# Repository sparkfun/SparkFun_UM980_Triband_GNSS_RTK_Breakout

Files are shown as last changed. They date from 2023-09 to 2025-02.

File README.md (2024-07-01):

SparkFun Triband GNSS RTK Breakout - UM980
===========================================================

SparkFun Triband GNSS RTK Breakout - UM980 (https://www.sparkfun.com/products/23286)

[*SparkFun Triband GNSS RTK Breakout - UM980 (GPS-23286)*](https://www.sparkfun.com/products/23286)

The SparkFun Triband GNSS RTK Breakout features the UM980 GNSS high precision RTK position module from Unicore Communications. The UM980 is a 1408-Channel GNSS Receiver based on the Nebulas IV™ that is able to simultaneously track GPS L1/L2/L5, GLONASS L1/L2, Galileo E1/E5a/E5b/E6, Beidou B1I/B2I/B3I/B1C/B2a/B2b, QZSS L1/L2/L5, and SBAS. With this board, you will be able to know where your (or any object's) X, Y, and Z location is within roughly the width of your fingernail. When an RTK solution is reached, the module can achieve a horizontal accuracy of about 8mm (~0.3 inches) and vertical accuracy of 15mm (~0.59 inches). The UM980 is capable of both rover and base station operations.

We've included a rechargeable backup battery to keep the latest module configuration and satellite data available. This battery helps 'warm-start' the module, decreasing the time-to-first-fix dramatically. This module features a survey-in mode, allowing the module to become a base station and produce RTCM 3.x correction data. A SMA connector is included for a secure connection to a Triband GNSS antenna.

Currently, serial UART is only supported on the UM980 module. All three serial UART ports have been broken out to the USB-C connector via CH340, 4-pin locking JST connector, and BlueSMiRF header. Unique pins have also been broken out to the edge of the board. Various jumpers are also included to configure power and LEDs.

Repository Contents
-------------------

* **.github/workflows** - YAML files used for GitHub Actions and GitHub Pages/mkdocs
* **/Firmware** - UM980 Firmware packages
* **/Documents** - Datasheets and various documents related to the UM980
* **/Hardware** - Eagle files
* **/Software** - Related software for the UM980
* **/docs** - Online documentation files
  * **/assets** - Folder containing all the file assets used for product documentation
    * **/board_files** - Copy of design files used for product documentation
    * **/component_documentation** - Datasheets and manuals for hardware components
    * **/img** - Images for product documentation
  * **/github** - Files stating how to contribute and filing issues used for product documentation
  * **/javascript** - Folder containing custom javascript used for product documentation
  * **/stylesheet** - Folder containing CSS files used for product documentation
* **/overrides** - Customization files used for product documentation
  * **/.icons** - Icons used for GitHub used for product documentation
  * **./partials** - Used for product documentation

Documentation
--------------

* **[Installing an Arduino Library Guide](https://learn.sparkfun.com/tutorials/installing-an-arduino-library)** - Basic information on how to install an Arduino library.
* **[Library](https://github.com/sparkfun/SparkFun_Unicore_GNSS_Arduino_Library/)** - Unicore GNSS Arduino Library
* **[Hookup Guide](https://docs.sparkfun.com/SparkFun_UM980_Triband_GNSS_RTK_Breakout/)** - Hookup guide for the SparkFun Triband GNSS RTK Breakout - UM980.
* **[How to Update Firmware on a Unicore GNSS Receiver](https://docs.sparkfun.com/Update_Firmware_Unicore_GNSS_Receiver/introduction/)** - Tutorial on how to update firmware on a Unicore GNSS Receiver. This is a general tutorial that covers the RTK Torch and UM980 breakout. Note that this information also included in the SparkFun Triband GNSS RTK Breakout - UM980 Hookup Guide.

License Information
-------------------

This product is _**open source**_! 

Various bits of the code have different licenses applied. Anything SparkFun wrote is beerware; if you see me (or any other SparkFun employee) at the local, and you've found our code helpful, please buy us a round!

Please use, reuse, and modify these files as you see fit. Please maintain attribution to SparkFun Electronics and release anything derivative under the same license.

Distributed as-is; no warranty is given.

- Your friends at SparkFun.

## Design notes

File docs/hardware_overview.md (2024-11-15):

In this section, we will highlight the hardware and pins that are broken out on the SparkFun Triband GNSS RTK Breakout - UM980. For more information, check out our [Resources and Going Further](../resources/) for the UM980.

<div style="text-align: center;">
  <table>
    <tr style="vertical-align:middle;">
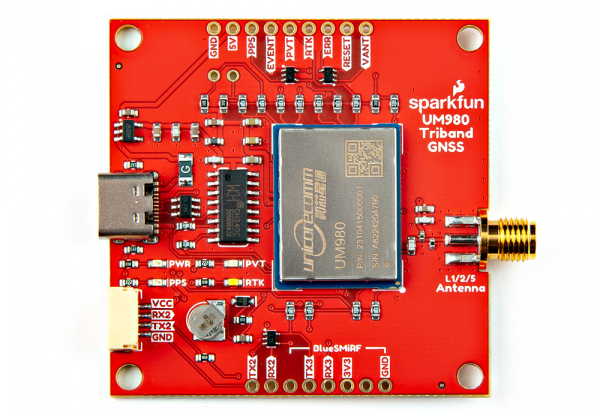
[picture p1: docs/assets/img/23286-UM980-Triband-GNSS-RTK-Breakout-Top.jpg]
     <td style="text-align: center; vertical-align: middle;"></td>
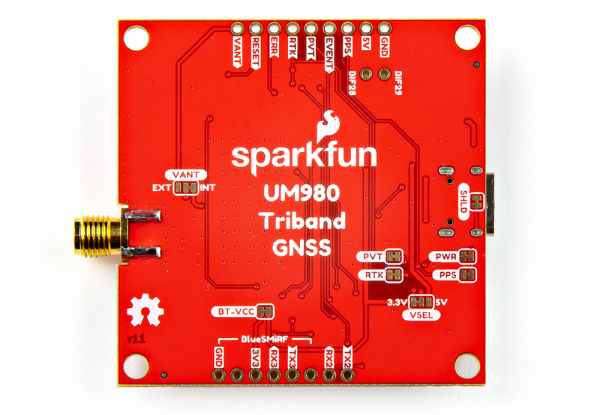
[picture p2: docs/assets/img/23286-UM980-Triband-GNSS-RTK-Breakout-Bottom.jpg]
Bottom View
     <td style="text-align: center; vertical-align: middle;"></td>
    </tr>
    <tr style="vertical-align:middle;">
     <td align="center">Top View</td>
     <td align="center">Bottom View</td>
    </tr>
  </table>
</div>

### UM980 Module

The board breaks out the UM980 which is an all-constellation, all-frequency, high precision RTK positioning module. This module has a low power consumption of about ~480mW.

<div style="text-align: center;">
  <table>
    <tr style="vertical-align:middle;">
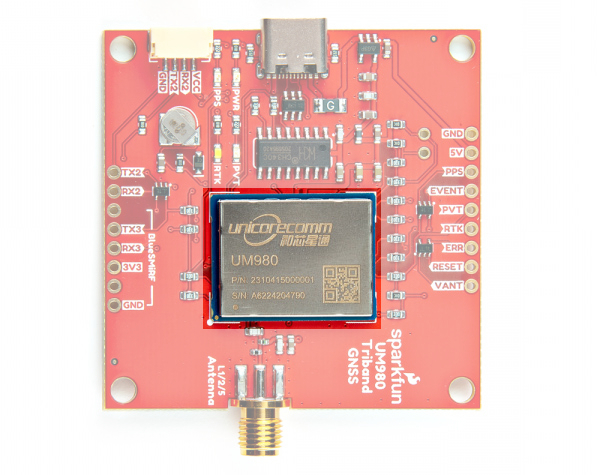
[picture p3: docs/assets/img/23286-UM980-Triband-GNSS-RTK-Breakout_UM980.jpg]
UM980 Module
     <td style="text-align: center; vertical-align: middle;"></td>
    </tr>
  </table>
</div>

The UM980 is a 1408-Channel GNSS Receiver based on the Nebulas IV&trade; that is able to simultaneously track multiple constellation for L1, L2, and L5 bands.

* Concurrent reception of GPS, GLONASS, Galileo, BeiDou, QZSS
    * GPS: L1C/A, L1C<sup>*</sup>, L2P(Y), L2C, L5
    * GLONASS: L1, L2
    * Galileo: E1, E5a, E5b, E6<sup>*</sup>
    * Beidou: B1I, B2I, B3I, B1C, B2a, B2b<sup>*</sup>
    * QZSS: L1/L2/L5
    * SBAS<br/><br/>

<sub>*: Items marked with * are only supported by specific firmware.</sub>

<div style="text-align: center;">
  <table>
    <tr style="vertical-align:middle;">
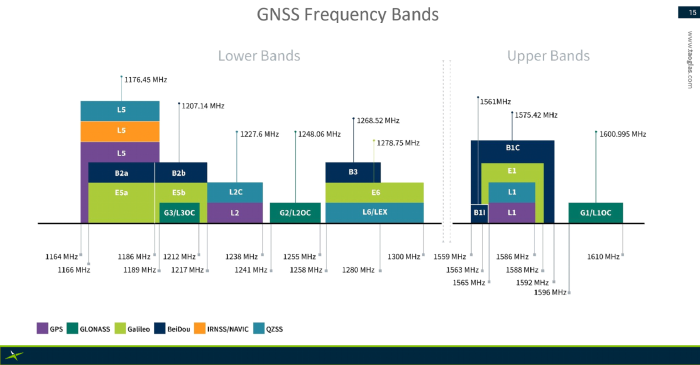
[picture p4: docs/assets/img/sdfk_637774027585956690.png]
L1, L2, L5 GNSS Frequency Bands
     <td style="text-align: center; vertical-align: middle;"></td>
    </tr>
    <tr style="vertical-align:middle;">
     <td style="text-align: center; vertical-align: middle;">Image Courtesy of <a href="https://www.everythingrf.com/community/navigating-the-l1-l2-and-l5-band-options-for-gnss">everythingRF</a></td>
    </tr>
  </table>
</div>

When a RTK solution is reached, the module can achieve a horizontal accuracy of about 8mm (~0.3 inches) and vertical accuracy of 15mm (~0.59 inches). The UM980 is capable of both rover and base station operations. Below are a few specs taken from the datasheet. For more information, check out the related [documents for the UM980 in the Resources](../resources/).

* Horizontal Accuracy
    * Autonomous: 1.5m
    * DGPS: 0.4m
    * RTK: 0.8cm + 1ppm
* Vertical Accuracy
    * Autonomous: 2.5m
    * DGPS: 0.8m
    * RTK: 1.5cm + 1ppm
* 50Hz Data Update Rate<sup>*</sup>
* Time-To-First-Fix:
    * Cold: 30s
    * Warm: 20s
    * Hot: 5s
* CoCom Limits
    * Max Altitude: 18000m
    * Max G: &lt;5G
    * Max Velocity: 515m/s
* Velocity Accuracy (RMS): 0.03m/s
* Time Accuracy (RMS): 20ns<br /><br />

<sub>*: Items marked with * are only supported by specific firmware.</sub>

### Power

There are a variety of power and power-related nets broken out to connectors and through hole pads. Power is regulated down to 3.3V with the AP2122K 3.3V/600mA voltage regulator. The logic levels for the UM980 is 3.3V for the I/O pins.

* **5V** &mdash; Power from the USB C connector's VBUS provides power to the 5V bus. A resettable fuse is connected between the two nets The 5V net is also connected to the edge PTH pin labelled as **5V** and the input of the 3.3V voltage regulator. Care must be taken when connecting to this pin to avoid conflicting voltages between the breakout board and anything connect to the 5V pin. Note that if users cut the default trace on **VSEL** and add solder between the center pad and pad labeled as **5V**, the JST locking connector will provide 5V to any device connected on that port as well.
* **VCC** &mdash; The VCC pin on the JST locking connector provides 3.3V by default to any device that is connected to this port. Users can adjust this voltage by cutting the default trace on the **VSEL** jumper, and adding a solder blob between the center pad and pad labeled as **5V**.
* **3V3** &mdash; The 3V3 pin under the BlueSMiRF provides 3.3V to the any serial device that is connected. If a serial device that is connecting to this port has its own power supply, make sure to cut the trace on the **BT-VCC** jumper on the back to avoid conflicting voltages.
* **VANT** &mdash; The voltage antenna (**VANT**) pin connects to the **VANT** jumper's **EXT** pad. This will provide power to an active antenna on the SMA connector if users cut the default trace on the **VANT** jumper, and add a solder blob between the center pad and pad labeled as **EXT**.
* **GND** &mdash; Of course, is the common, ground voltage (0V reference) for the system.

<div style="text-align: center;">
  <table>
    <tr style="vertical-align:middle;">
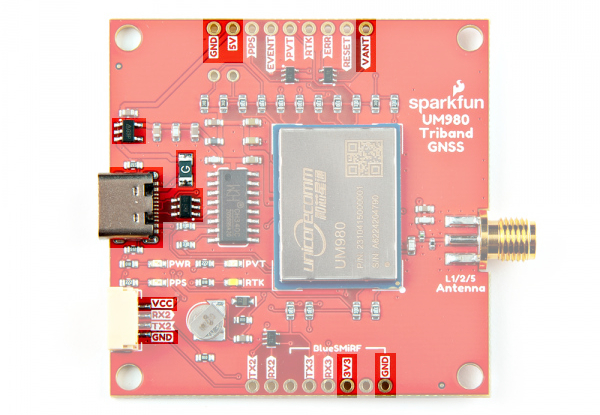
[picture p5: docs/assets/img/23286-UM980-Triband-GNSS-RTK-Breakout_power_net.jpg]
Power Nets Highlighted
     <td style="text-align: center; vertical-align: middle;"></td>
    </tr>
  </table>
</div>

### Backup Battery

The small metal disk is a small 3V/1mAh lithium battery. This battery does not provide power to the IC like the 3.3V system does, but to relevant systems inside the IC that allow for a quick reconnection to satellites. The first time to fix (TTFF) is about ~30 seconds. With the backup battery, the warm start is less than 20 seconds and the hot start is less than 5 seconds.

<div style="text-align: center;">
  <table>
    <tr style="vertical-align:middle;">
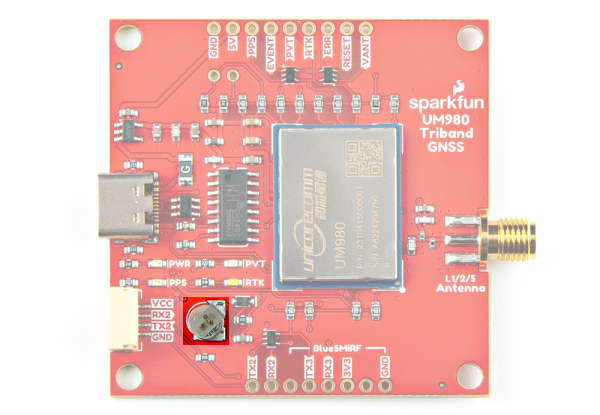
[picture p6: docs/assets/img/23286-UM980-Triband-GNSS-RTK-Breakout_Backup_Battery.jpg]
Backup Battery Highlighted
     <td style="text-align: center; vertical-align: middle;"></td>
    </tr>
  </table>
</div>

### CH340 USB-to-Serial Converter

The top side of the board includes a CH340 USB-to-serial converter connected to the serial UART1 port. The chip can be used to send serial data between the device and computer. You can view the output or configure the device through a serial terminal. When using the UM980 with Unicore's UPrecise Software, you can also initiate firmware updates.

<div style="text-align: center;">
  <table>
    <tr style="vertical-align:middle;">
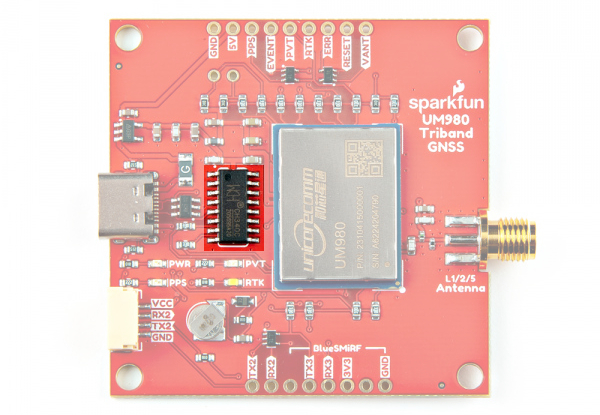
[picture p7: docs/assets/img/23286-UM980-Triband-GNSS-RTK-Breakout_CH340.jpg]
CH340 Highlighted on the TriBand GNSS RTK Breakout Board - UM980
     <td style="text-align: center; vertical-align: middle;"></td>
    </tr>
  </table>
</div>

The CH340 driver should automatically install on most operating systems. However, there is a wide range of operating systems out there. You may need to install drivers the first time you connect the chip to your computer's USB port or when there are operating system updates. For more information, check out our [How to Install CH340 Drivers Tutorial](https://learn.sparkfun.com/tutorials/how-to-install-ch340-drivers).

<div style="text-align: center">
  <table>
    <tr>
      <td style="text-align: center; vertical-align: middle;">
        <a href="https://learn.sparkfun.com/tutorials/how-to-install-ch340-drivers">
          <div style="text-align: center">How to Install CH340 Drivers</div>
          <hr />
          <h3 style="text-align: left">
            <b>How to Install CH340 Drivers</b>
          </h3>
        </a>
      </td>
    </tr>
  </table>
</div>

### Serial UARTs

!!! note
    Current serial UART is only supported on the UM980 module. I<sup>2</sup>C, SPI, and CAN have been reserved on the module but are not currently supported.

There are three serial UART ports available on the breakout board. Serial UART1 is connected to the CH340 USB-to-serial converter as stated earlier. Serial UART2 is connected to the 4-pin locking JST connector. Tx and Rx are also broken out as PTHs. We recommend using a compatible cable to connect to the locking JST connector to save time connecting to a microcontroller. Serial UART3 is connected to the PTH pins labeled as BlueSMiRF on the edge of the board.

<div style="text-align: center;">
  <table>
    <tr style="vertical-align:middle;">
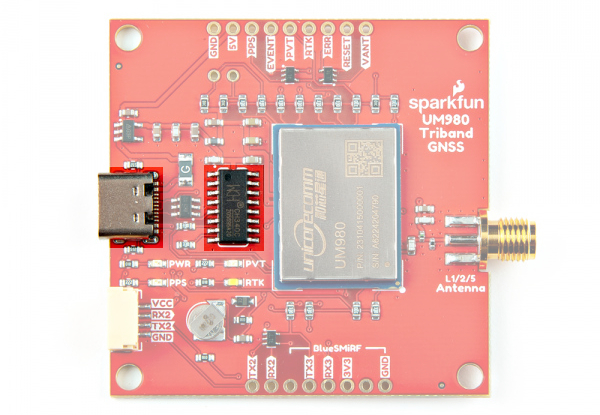
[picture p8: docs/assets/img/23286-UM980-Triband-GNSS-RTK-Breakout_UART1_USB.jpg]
UART1 via USB
     <td style="text-align: center; vertical-align: middle;"></td>
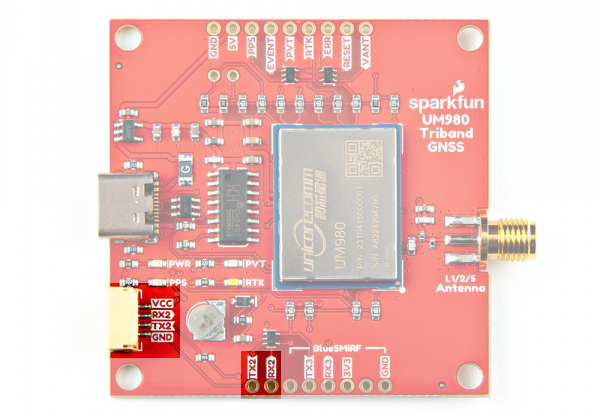
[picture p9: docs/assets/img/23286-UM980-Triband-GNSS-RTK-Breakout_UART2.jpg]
UART2
     <td style="text-align: center; vertical-align: middle;"></td>
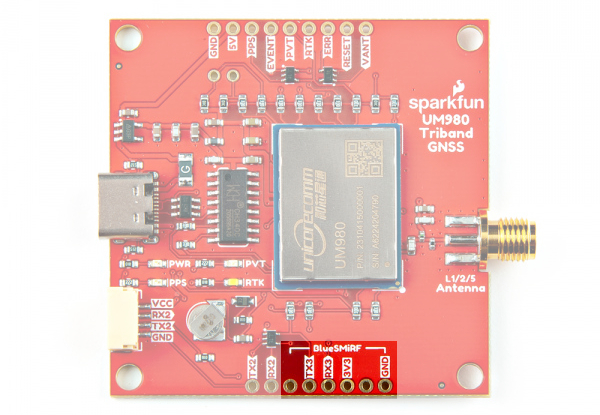
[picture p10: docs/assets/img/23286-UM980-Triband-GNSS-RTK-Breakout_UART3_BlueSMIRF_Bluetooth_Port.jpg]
UART3
     <td style="text-align: center; vertical-align: middle;"></td>
    </tr>
    <tr style="vertical-align:middle;">
     <td align="center">UART1</td>
     <td align="center">UART2</td>
     <td align="center">UART3</td>
    </tr>
  </table>
</div>

!!! note "What is a BlueSMiRF?"
    The BlueSMiRF was a Bluetooth device that was included in SparkFun's catalog. The footprint consists of a 1x6 header for the serial UART and power pins. Note that the arrangement of the header pins is different from USB-to-serial converters (i.e. FTDI Serial Breakout Boards and CH340 Serial Basics Boards).

### SMA Connector

The board is populated with one SMA connector for a secure connection. You will need a multiband GNSS antenna capable of receiving L1, L2, and L5 bands to get the most out of the UM980. Note that this is intended for active antennas. We recommend using the
[GNSS Multi-Band L1/L2/L5 Surveying Antenna - TNC (SPK6618H)](https://www.sparkfun.com/products/21801) as it includes a built-in ground plane and [SMA Male to TNC Male interface cable](https://www.sparkfun.com/products/17833).

<div style="text-align: center;">
  <table>
    <tr style="vertical-align:middle;">
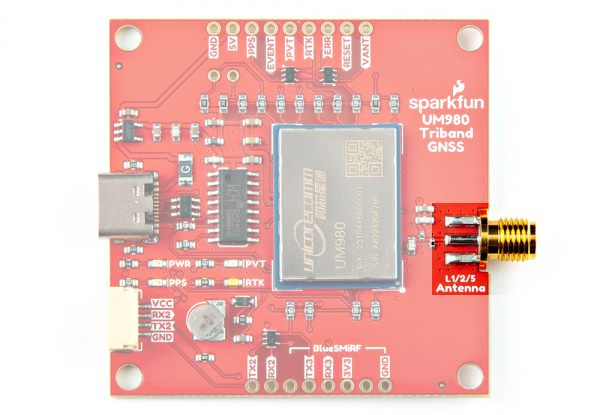
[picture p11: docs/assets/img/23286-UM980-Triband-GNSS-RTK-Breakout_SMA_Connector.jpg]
SMA Connector Highlighted
     <td style="text-align: center; vertical-align: middle;"></td>
    </tr>
  </table>
</div>

### Breakout Pins

Besides the power and serial UART pins, the following pins are also broken out on the edge of the breakout board.

* **PPS** &mdash; The **PPS** output pin provides a pulse per second when there is a satellite lock.  When the UM980 losses a satellite lock, the PPS will continue to blink for about 1 minute. Note that output pulse width and polarity can vary depending on the UM980's configuration. Make sure to check the Unicore Reference Commands Manual for more information.
* **EVENT** &mdash; The **EVENT** input pin and has an adjustable frequency and polarity.
* **PVT** &mdash; The **PVT** pin is a status pin and active high. This outputs high when positioning and low when not positioning. This is connected to an LED as well and will light up whenever the pin is high.
* **RTK** &mdash; The **RTK** pin is a status pin and active high. This outputs high for an RTK fixed solution, and low with other positioning status or no positioning. This is connected to an LED as well and will light up whenever the pin is high.
* **ERR** &mdash; The **ERROR** pin is active high when there is an error or failing self-detection. The pin is low when passing.
* **RESET** &mdash; The **RESET** pin is active low and resets the UM980. The recommended active time should be no less than 5ms.
* **BIF29** &mdash; The **BIF29** stands for the built-in function that was broken out from the UM980&apos;s pin 29. This is connected to a 10k&ohm; pull-up resistor that was recommended as part of the design as a testing point. Note that this pin cannot connect to ground, power, or a peripheral I/O.
* **BIF28** &mdash; The **BIF28** stands for the built-in function that was broken out from the UM980&apos;s pin 28. This is connected to a 10k&ohm; pull-up resistor that was recommended as part of the design as a testing point. Note that this pin cannot connect to ground, power, or a peripheral I/O.

<div style="text-align: center;">
  <table>
    <tr style="vertical-align:middle;">
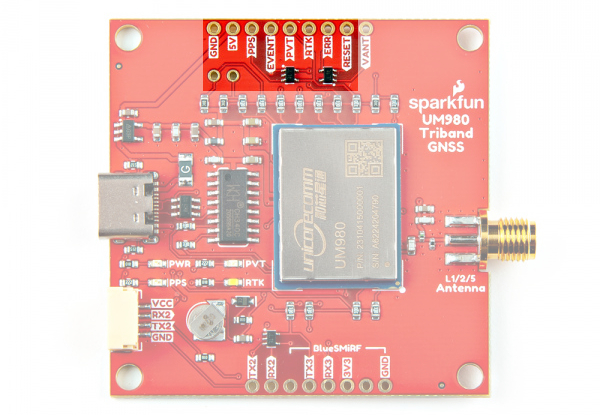
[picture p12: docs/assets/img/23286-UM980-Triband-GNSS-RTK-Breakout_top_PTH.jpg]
     <td style="text-align: center; vertical-align: middle;"></td>
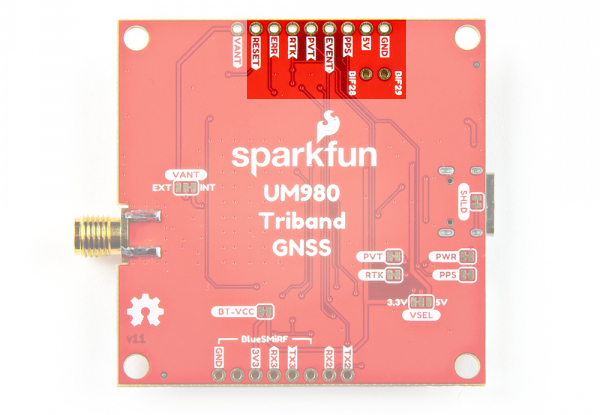
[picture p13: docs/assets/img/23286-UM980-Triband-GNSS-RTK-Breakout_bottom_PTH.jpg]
Bottom View
     <td style="text-align: center; vertical-align: middle;"></td>
    </tr>
    <tr style="vertical-align:middle;">
     <td align="center">Top View of Breakout Pins</td>
     <td align="center">Bottom View of Breakout Pins</td>
    </tr>
  </table>
</div>

### LEDs

The board includes the following status LEDs as indicated in the image below.

* **PWR** &mdash; The power LED is connected to 3.3V and lights up with there is power on the board. Users can disable this LED by cutting the trace connecting the **PWR** jumper.
* **PVT** &mdash; The PVT LED is connected to the PVT pin. This lights up when positioning. Users can disable this LED by cutting the trace connecting the **PVT** jumper.
* **PPS** &mdash; By default, the **PPS** LED will blink when there is a satellite lock. When the UM980 losses a satellite lock, the PPS will continue to blink for about 1 minute. Note that output can vary depending on the UM980's configuration. Make sure to check the Unicore Reference Commands Manual for more information. Users can disable this LED by cutting the trace connecting the **PPS** jumper.
* **RTK** &mdash; The RTK LED lights up when there is an RTK fixed solution. Users can disable this LED by cutting the trace connecting the **RTK** jumper.

<div style="text-align: center;">
  <table>
    <tr style="vertical-align:middle;">
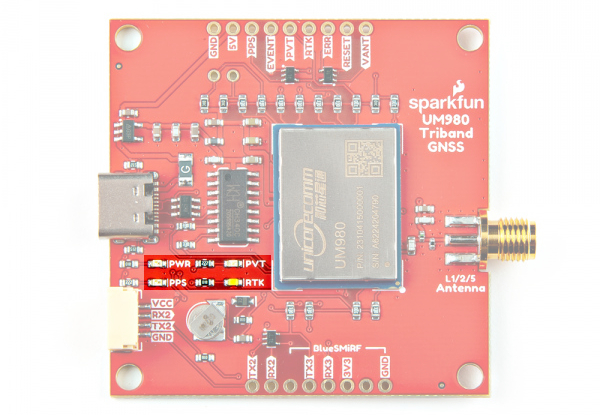
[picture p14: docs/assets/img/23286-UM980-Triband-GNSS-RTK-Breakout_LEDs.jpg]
LEDs Highlighted
     <td style="text-align: center; vertical-align: middle;"></td>
    </tr>
  </table>
</div>

### Jumpers

!!!note
    If this is your first time working with jumpers, check out the [How to Work with Jumper Pads and PCB Traces](https://learn.sparkfun.com/tutorials/how-to-work-with-jumper-pads-and-pcb-traces/all) tutorial for more information.

There are a few jumper pads available on the bottom of the board.

* **SHLD** &mdash; This jumper connects the USB Type C connector's shield pin to GND. Cut this to isolate the USB Type C connector's shield pin. This is for advanced users that want to ground their board to their enclosure instead of the ground plane.
* **VSEL** &mdash; This three way jumper sets voltage to the locking JST connector. By default, this is set to 3.3V. Cutting a trace and adding a solder blob between the center pad and the pad labeled as **5V** will set the voltage on the locking JST connector to 5V.
* **PWR** &mdash; By default, this jumper is closed. Cut this trace to disable the power LED that is connected to 3.3V.
* **PVT** &mdash; By default, this jumper is closed. Cut this trace to disable the PVT LED connected to PVT.
* **PPS** &mdash; By default, this jumper is closed. Cut this trace to disable the PPS LED connected to PPS.
* **RTK** &mdash; By default, this jumper is closed. Cut this trace to disable the RTK LED connected to RTK.
* **BT-VCC** &mdash; By default, this jumper is closed and connected to 3.3V. If a serial device that is connecting to this port has its own power supply, cut this trace to avoid conflicting voltages.
* **VANT** &mdash; This three way jumper sets the voltage source for the active antenna. By default, this is connected to the INT and uses voltage provided from the board (specifically the UM980's _VCC_RF_ pin). Cut this trace and add a solder blob between the center pad and the pad labeled as **EXT** to provide external power to your active antenna. Make sure to also provide power on the VANT PTH and connect GND from the external power supply the rest of the GND plane.

<div style="text-align: center;">
  <table>
    <tr style="vertical-align:middle;">
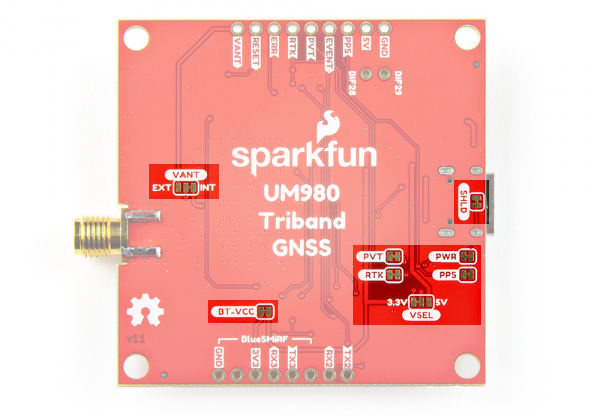
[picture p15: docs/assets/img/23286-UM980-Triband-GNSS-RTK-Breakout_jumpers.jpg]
Jumpers Highlighted
     <td style="text-align: center; vertical-align: middle;"></td>
    </tr>
  </table>
</div>

### 3D Model

A 3D model of the board and components were exported to a STEP file using KiCad.

<!-- Import the component -->
<script type="module" src="https://ajax.googleapis.com/ajax/libs/model-viewer/3.5.0/model-viewer.min.js"></script>

<div style="text-align: center;">
    <model-viewer src="../assets/3d_model/SparkFun_GNSS_UM980_3D_model.glb" camera-controls poster="../assets/3d_model/SparkFun_GNSS_UM980_3D_image.png" environment-image="legacy" shadow-intensity="1.58" exposure="0.64" shadow-softness="0.24" tone-mapping="neutral" camera-orbit="-46.67deg 57.14deg 153.3m" field-of-view="30deg" style="width: 750px; height: 500px;">
    </model-viewer>
</div>
<br />
<div style="text-align: center">
    <a href="../assets/3d_model/SparkFun_GNSS_UM980_3D_model.step" target="stp_file" class="md-button">Click Here for the STEP File</a>
</div>

###Board Dimensions

The board is 2.0" x 2.0" (50.8mm x 50.8mm). There are 4x mounting holes by each corner of the board.

<div style="text-align: center;">
  <table>
    <tr style="vertical-align:middle;">
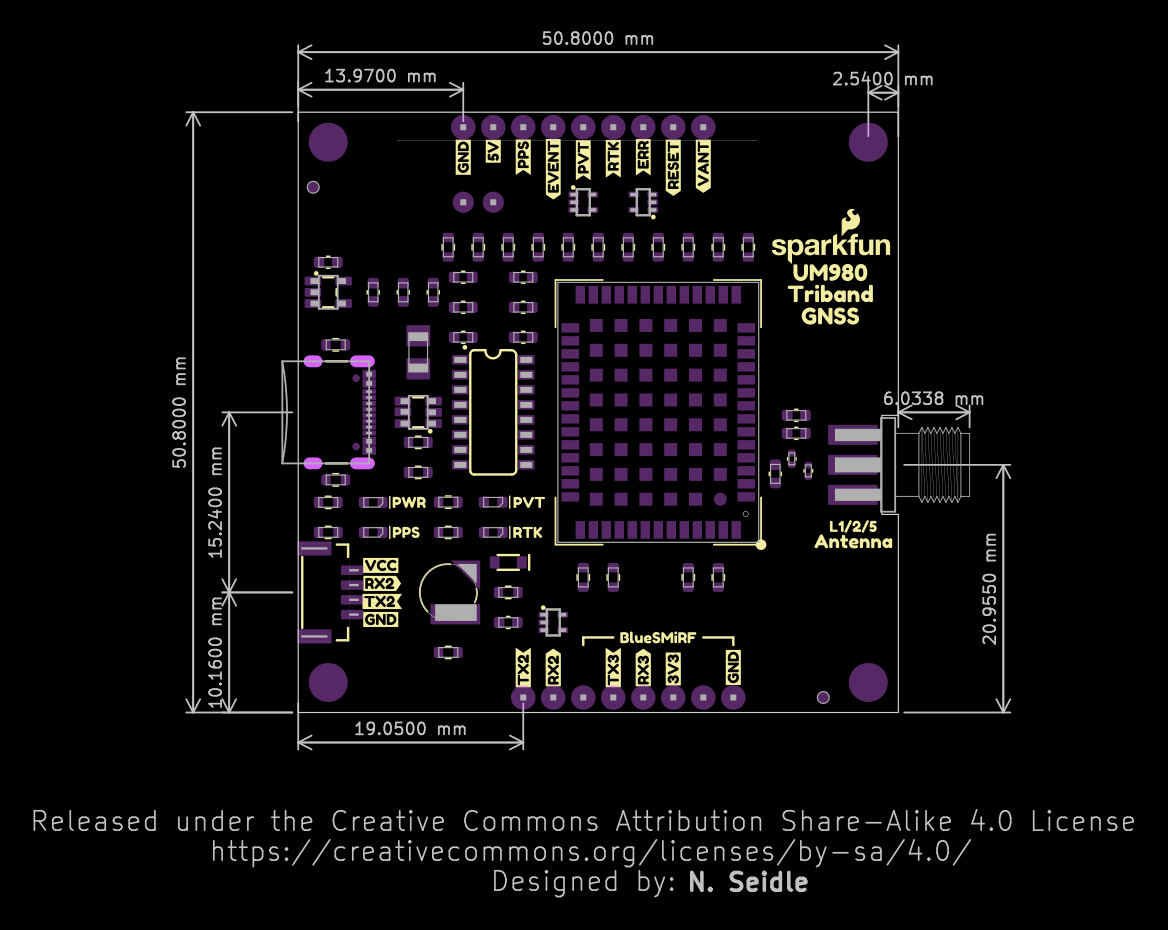
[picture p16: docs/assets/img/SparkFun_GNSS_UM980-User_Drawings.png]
Board Dimensions
     <td style="text-align: center; vertical-align: middle;"></td>
    </tr>
  </table>
</div>

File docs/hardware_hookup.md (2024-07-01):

In this section, we'll go over how to connect the Triband GNSS Antenna, GNSS RTK Breakout - UM980, and IoT RedBoard - ESP32 for embedded systems. Of course, you can also connect the UM980 directly to your computer without the need for a microcontroller if you decide to use the UPrecise Software as well.

### L1/L2/L5 Multiband GNSS Antenna

Connect a compatible multi-band antenna that is capable of receiving L1, L2, and L5 bands. In this case, we used the "GNSS Multi-Band L1/L2/L5 Surveying Antenna - TNC (SPK6618H)." This also has a ground plane embedded in the antenna. Insert the TNC side of the interface cable into the antenna's TNC connector. Secure the connection by tightening the screw until it is finger-tight. Then insert the SMA side of the interface cable into the Triband GNSS RTK Breakout's SMA connector. Secure the connection by using the SMA's hex nut until it is finger-tight.

<div style="text-align: center;">
  <table>
    <tr style="vertical-align:middle;">
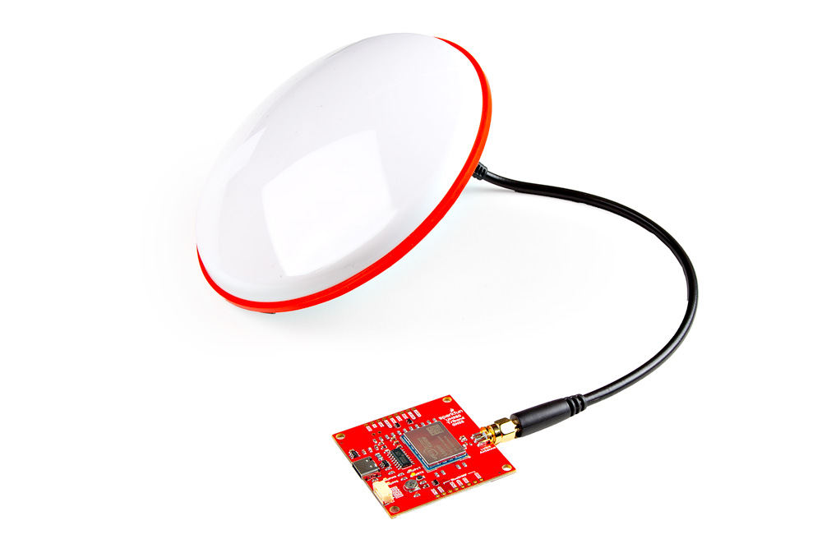
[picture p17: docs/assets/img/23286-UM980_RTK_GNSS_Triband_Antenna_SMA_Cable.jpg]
Adapter cable between Antenna and Breakout Board
     <td style="text-align: center; vertical-align: middle;"></td>
    </tr>
  </table>
</div>

!!! note
    For users that are using a different multiband antenna, you may need to include a [antenna ground plate](https://www.sparkfun.com/products/17519) to get the most of the multi-band antenna.

!!! note
    Not all multiband antennas are made the same! Make sure that you are connecting a multi-band antenna that is capable of receiving L1/L2/L5 signals when using the Triband GNSS RTK Breakout - UM980.

### Microcontroller

!!! note
    The Arduino Library was written and tested with the ESP32 processor. We recommend using the IoT RedBoard - ESP32 for the scope of this tutorial.

For users using the breakout board in embedded applications, you will need to plug in the JST-GHR-04V Cable to the Triband GNSS RTK Breakout - UM980. You will then need to connect the other end to a microcontroller to process the data. In this case, we used the IoT RedBoard - ESP32.

<div style="text-align: center;">
    <table>
        <tr>
            <th style="text-align: center; border: solid 1px #cccccc;">IoT RedBoard - ESP32
            </th>
            <th style="text-align: center; border: solid 1px #cccccc;"> Triband GNSS RTK Breakout - UM980
            </th>
        </tr>
        <tr>
            <td style="text-align: center; border: solid 1px #cccccc;" bgcolor="#f2dede"><font color="#000000">3V3</font>
            </td>
            <td style="text-align: center; border: solid 1px #cccccc;" bgcolor="#f2dede"><font color="#000000">3.3V</font>
            </td>
        </tr>
        <tr>        
            <td style="text-align: center; border: solid 1px #cccccc;" bgcolor="#d4edda"><font color="#000000">UART1_TX (D4)</font>
            </td>
            <td style="text-align: center; border: solid 1px #cccccc;" bgcolor="#d4edda"><font color="#000000">RX2</font>
            </td>
        </tr>
        <tr>        
            <td style="text-align: center; border: solid 1px #cccccc;" bgcolor="#ffdaaf"><font color="#000000">UART1_RX (D13)</font>
            </td>
            <td style="text-align: center; border: solid 1px #cccccc;" bgcolor="#ffdaaf"><font color="#000000">TX2</font>
            </td>
        </tr>
        <tr>
            <td style="text-align: center; border: solid 1px #cccccc;" bgcolor="#DDDDDD"><font color="#000000">GND</font>
            </td>
            <td style="text-align: center; border: solid 1px #cccccc;" bgcolor="#DDDDDD"><font color="#000000">GND</font>
            </td>
        </tr>
    </table>
</div>

<div style="text-align: center;">
  <table>
    <tr style="vertical-align:middle;">
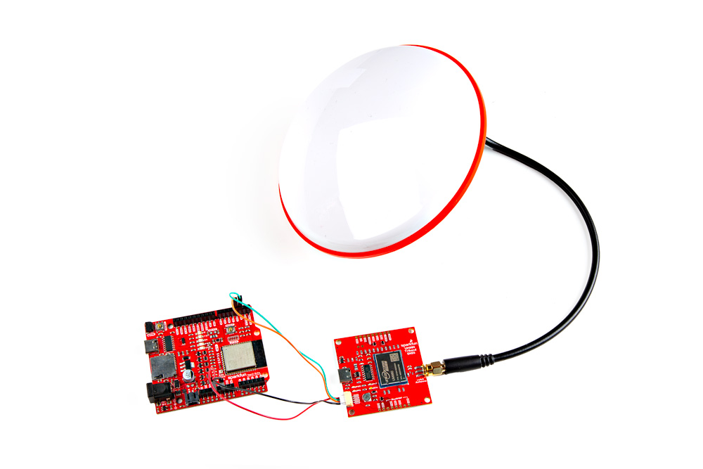
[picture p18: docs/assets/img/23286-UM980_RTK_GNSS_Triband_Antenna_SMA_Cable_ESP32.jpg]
UM980 to Microcontroller with USB
     <td style="text-align: center; vertical-align: middle;"></td>
    </tr>
  </table>
</div>

### USB to Microcontroller

To power and program the IoT RedBoard - ESP32, users will just need to insert the Type C side of the cable to the development board. The other end will connect to a computer's USB port.

<div style="text-align: center;">
  <table>
    <tr style="vertical-align:middle;">
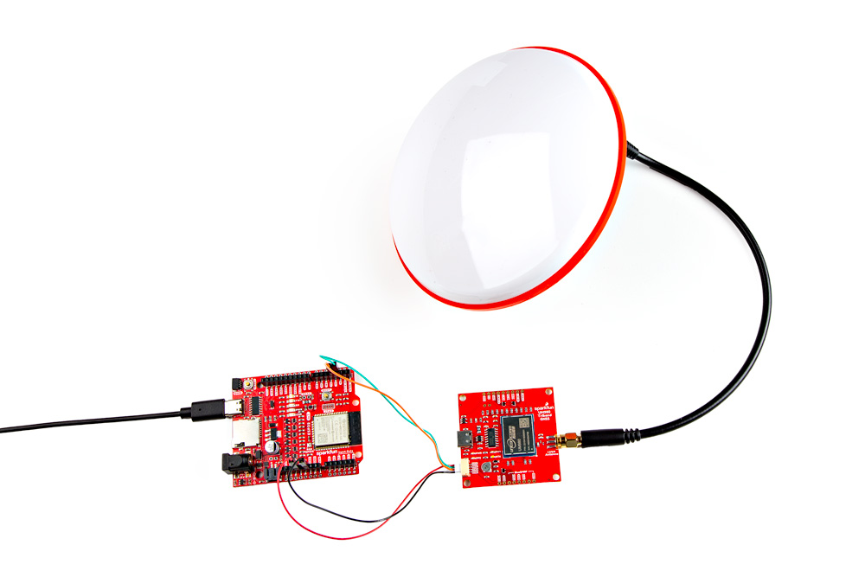
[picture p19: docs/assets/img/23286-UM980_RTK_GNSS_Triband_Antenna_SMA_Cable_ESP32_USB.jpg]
USB Cable Inserted into IoT RedBoard - ESP32 and Triband GNSS RTK Breakout UM980
     <td style="text-align: center; vertical-align: middle;"></td>
    </tr>
  </table>
</div>

### USB to Triband GNSS RTK Breakout - UM980

For users that simply want to connect to the board via USB, you will insert a USB C cable into the USB connector. Then connect the other end to your computer USB port.

<div style="text-align: center;">
  <table>
    <tr style="vertical-align:middle;">
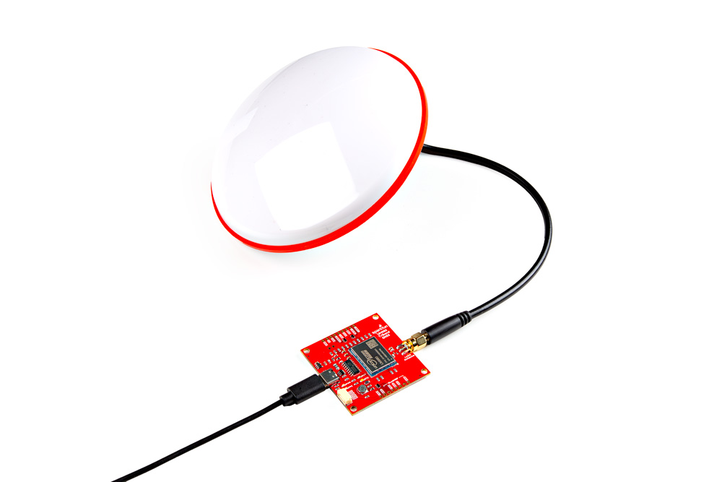
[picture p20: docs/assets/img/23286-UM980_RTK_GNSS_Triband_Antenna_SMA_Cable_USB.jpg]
USB Cable Inserted into Triband GNSS RTK Breakout UM980
     <td style="text-align: center; vertical-align: middle;"></td>
    </tr>
  </table>
</div>

### Connecting via PTH

For temporary connections to the PTHs, you could use IC hooks to test out the pins. However, you'll need to solder headers or wires of your choice to the board for a secure connection. You can choose between a combination of [header pins and jumper wires](https://learn.sparkfun.com/tutorials/how-to-solder-through-hole-soldering/all), or [stripping wire and soldering the wire](https://learn.sparkfun.com/tutorials/working-with-wire/all) directly to the board.

<div class="grid cards col-4" markdown>

-   <a href="https://learn.sparkfun.com/tutorials/how-to-solder-through-hole-soldering/all">
      <figure markdown>
        How to Solder: Through Hole Soldering
      </figure>
    </a>

    ---

    <a href="https://learn.sparkfun.com/tutorials/how-to-solder-through-hole-soldering/all">
      <b>How to Solder: Through Hole Soldering</b>
    </a>
<!-- ----------WHITE SPACE BETWEEN GRID CARDS---------- -->

-   <a href="https://learn.sparkfun.com/tutorials/working-with-wire/all">
      <figure markdown>
        Working with Wire
      </figure>
    </a>

    ---

    <a href="https://learn.sparkfun.com/tutorials/working-with-wire/all">
      <b>Working with Wire</b>
    </a>
<!-- ----------WHITE SPACE BETWEEN GRID CARDS---------- -->
</div>

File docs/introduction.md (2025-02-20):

The [SparkFun Triband GNSS RTK Breakout features the UM980](https://www.sparkfun.com/products/23286) GNSS high precision RTK position module from Unicore Communications. The UM980 is a 1408-Channel GNSS Receiver based on the Nebulas IV&trade; that is able to simultaneously track GPS L1/L2/L5, GLONASS L1/L2, Galileo E1/E5a/E5b/E6, Beidou B1I/B2I/B3I/B1C/B2a/B2b, QZSS L1/L2/L5, and SBAS. With this board, you will be able to know where your (or any object's) X, Y, and Z location is within roughly the width of your fingernail. When an RTK solution is reached, the module can achieve a horizontal accuracy of about 8mm (~0.3 inches) and vertical accuracy of 15mm (~0.59 inches). The UM980 is capable of both rover and base station operations.

<center>
<div class="grid cards" style="width:500px;" markdown>

-   <a href="https://www.sparkfun.com/products/23286">
      <figure markdown>
        SparkFun Triband GNSS RTK Breakout - UM980
      </figure>
    </a>

    ---

    <a href="https://www.sparkfun.com/products/23286">
      <b>SparkFun Triband GNSS RTK Breakout - UM980</b>
      <br />
      GPS-23286
      <br />
      <center>[Purchase from SparkFun :fontawesome-solid-cart-plus:](https://www.sparkfun.com/products/23286){ .md-button .md-button--primary }</center>
    </a>

</div>
</center>

<div style="text-align: center;">
  <iframe width="560" height="315" src="https://www.youtube.com/embed/JRmVSYMMBFU?si=3qFl3sWRnnz5FLNi" title="YouTube video player" frameborder="0" allow="accelerometer; autoplay; clipboard-write; encrypted-media; gyroscope; picture-in-picture; web-share" allowfullscreen></iframe>
</div>

In this tutorial, we'll go over the hardware and how to hookup the breakout board. We will also go over the Arduino examples to get started.

### Required Materials

To follow along with this tutorial, you will need the following materials. You may not need everything though depending on what you have. Add it to your cart, read through the guide, and adjust the cart as necessary.

* 1x [SparkFun IoT RedBoard - ESP32 Development Board [WRL-19177]](https://www.sparkfun.com/products/19177)
* 1x [Reversible USB A to C Cable - 0.8m [CAB-15425]](https://www.sparkfun.com/products/15425)
* 1x [Breadboard to JST-GHR-04V Cable - 4-Pin x 1.25mm Pitch [CAB-17240]](https://www.sparkfun.com/products/17240)
* 1x [SparkFun Triband GNSS RTK Breakout - UM980 [GPS-23286]](https://www.sparkfun.com/products/23286)
* 1x [Reinforced Interface Cable - SMA Male to TNC Male (10m) [CAB-21740]](https://www.sparkfun.com/products/21740)
* 1x [GNSS Multi-Band L1/L2/L5 Surveying Antenna - TNC (SPK6618H) [GPS-21801]](https://www.sparkfun.com/products/21801)

<div class="grid cards col-4" markdown>

<!-- ----------WHITE SPACE BETWEEN PRODUCTS---------- -->
-   <a href="https://www.sparkfun.com/products/19177">
      <figure markdown>
        SparkFun IoT RedBoard - ESP32 Development Board
      </figure>
    </a>

    ---

    <a href="https://www.sparkfun.com/products/19177">
      <b>SparkFun IoT RedBoard - ESP32 Development Board</b>
      <br />
      WRL-19177
    </a>
<!-- ----------WHITE SPACE BETWEEN PRODUCTS---------- -->
-   <a href="https://www.sparkfun.com/products/15425">
      <figure markdown>
        Reversible USB A to C Cable - 0.8m
      </figure>
    </a>

    ---

    <a href="https://www.sparkfun.com/products/15425">
      <b>Reversible USB A to C Cable - 0.8m</b>
      <br />
      CAB-15425
    </a>
<!-- ----------WHITE SPACE BETWEEN PRODUCTS---------- -->
-   <a href="https://www.sparkfun.com/products/23286">
      <figure markdown>
        SparkFun Triband GNSS RTK Breakout - UM980
      </figure>
    </a>

    ---

    <a href="https://www.sparkfun.com/products/23286">
      <b>SparkFun Triband GNSS RTK Breakout - UM980</b>
      <br />
      GPS-23286
    </a>
<!-- ----------WHITE SPACE BETWEEN PRODUCTS---------- -->
-   <a href="https://www.sparkfun.com/products/17240">
      <figure markdown>
        Breadboard to JST-GHR-04V Cable - 4-Pin x 1.25mm Pitch
      </figure>
    </a>

    ---

    <a href="https://www.sparkfun.com/products/17240">
      <b>Breadboard to JST-GHR-04V Cable - 4-Pin x 1.25mm Pitch</b>
      <br>
      CAB-17240
    </a>
<!-- ----------WHITE SPACE BETWEEN PRODUCTS---------- -->
-   <a href="https://www.sparkfun.com/products/21740">
      <figure markdown>
        Reinforced Interface Cable - SMA Male to TNC Male (10m)
      </figure>
    </a>

    ---

    <a href="https://www.sparkfun.com/products/21740">
      <b>Reinforced Interface Cable - SMA Male to TNC Male (10m)</b>
      <br>
      CAB-21740
    </a>
<!-- ----------WHITE SPACE BETWEEN PRODUCTS---------- -->
-   <a href="https://www.sparkfun.com/products/21801">
      <figure markdown>
        GNSS Multi-Band L1/L2/L5 Surveying Antenna - TNC (SPK6618H)
      </figure>
    </a>

    ---

    <a href="https://www.sparkfun.com/products/21801">
      <b>GNSS Multi-Band L1/L2/L5 Surveying Antenna - TNC (SPK6618H)</b>
      <br>
      GPS-21801
    </a>
<!-- ----------WHITE SPACE BETWEEN PRODUCTS---------- -->
</div>

### GNSS Accessories &nbsp;_(Optional)_

Depending on your setup, you may need the following mounting hardware. Note that the antenna ground plate is needed for tri-band antennas that do not have a ground plane.

* [GNSS Magnetic Mount [PRT-21257]](https://www.sparkfun.com/products/21257)
* [GNSS Antenna Mounting Hardware Kit [KIT-22197]](https://www.sparkfun.com/products/22197)
* [GPS Antenna Ground Plate [GPS-17519]](https://www.sparkfun.com/products/17519)

<div class="grid cards col-4" markdown>

-   <a href="https://www.sparkfun.com/products/21257">
      <figure markdown>
        GNSS Magnetic Antenna Mount - 5/8
      <br />
      TOL-21257
    </a>
<!-- ----------WHITE SPACE BETWEEN PRODUCTS---------- -->
-   <a href="https://www.sparkfun.com/products/22197">
      <figure markdown>
        GNSS Antenna Mounting Hardware Kit
      </figure>
    </a>

    ---

    <a href="https://www.sparkfun.com/products/22197">
      <b>GNSS Antenna Mounting Hardware Kit</b>
      <br />
      KIT-22197
    </a>
<!-- ----------WHITE SPACE BETWEEN PRODUCTS---------- -->
-   <a href="https://www.sparkfun.com/products/17519">
      <figure markdown>
        GPS Antenna Ground Plate
      </figure>
    </a>

    ---

    <a href="https://www.sparkfun.com/products/17519">
      <b>GPS Antenna Ground Plate</b>
      <br />
      GPS-17519
    </a>
<!-- ----------WHITE SPACE BETWEEN PRODUCTS---------- -->

</div>

### Radios &nbsp;_(Optional)_

For users that require radios to transmit RTK correction data, you could use the following radios.

* [SiK Telemetry Radio V3 - 915MHz, 100mW [WRL-19032]](https://www.sparkfun.com/products/19032)
* [SparkFun LoRaSerial Kit - 915MHz (Enclosed) [WRL-20029]](https://www.sparkfun.com/products/20029)

<div class="grid cards col-4" markdown>

-   <a href="https://www.sparkfun.com/products/19032">
      <figure markdown>
        SiK Telemetry Radio V3 - 915MHz, 100mW
      </figure>
    </a>

    ---

    <a href="https://www.sparkfun.com/products/19032">
      <b>SiK Telemetry Radio V3 - 915MHz, 100mW</b>
      <br />
      WRL-19032
    </a>
<!-- ----------WHITE SPACE BETWEEN PRODUCTS---------- -->
-   <a href="https://www.sparkfun.com/products/20029">
      <figure markdown>
        SparkFun LoRaSerial Kit - 915MHz (Enclosed)
      </figure>
    </a>

    ---

    <a href="https://www.sparkfun.com/products/20029">
      <b>SparkFun LoRaSerial Kit - 915MHz (Enclosed)</b>
      <br />
      WRL-20029
    </a>
<!-- ----------WHITE SPACE BETWEEN PRODUCTS---------- -->

</div>

### Tools &nbsp;_(Optional)_

You will need a soldering iron, solder, and [general soldering accessories](https://www.sparkfun.com/categories/49) for a secure connection when using the plated through holes.

* [Soldering Iron [TOL-14456]](https://www.sparkfun.com/products/14456)
* [Solder Lead Free - 15-gram Tube [TOL-9163]](https://www.sparkfun.com/products/9163)
* [Flush Cutters - Xcelite [TOL-14782]](https://www.sparkfun.com/products/14782)
* [Hook-Up Wire - Assortment (Stranded, 22 AWG) [PRT-11375]](https://www.sparkfun.com/products/11375)
* [Wire Stripper - 20-30 AWG Solid (22-32 AWG Stranded) [TOL-22263]](https://www.sparkfun.com/products/22263)

<div class="grid cards col-4" markdown>

-   <a href="https://www.sparkfun.com/products/14456">
      <figure markdown>
        Soldering Iron - 60W (Adjustable Temperature)
      </figure>
    </a>

    ---

    <a href="https://www.sparkfun.com/products/14456">
      <b>Soldering Iron - 60W (Adjustable Temperature)</b>
      <br />
      TOL-14456
    </a>
<!-- ----------WHITE SPACE BETWEEN PRODUCTS---------- -->
-   <a href="https://www.sparkfun.com/products/9163">
      <figure markdown>
        Solder Lead Free - 15-gram Tube
      </figure>
    </a>

    ---

    <a href="https://www.sparkfun.com/products/9163">
      <b>Solder Lead Free - 15-gram Tube</b>
      <br>
      TOL-09163
    </a>
<!-- ----------WHITE SPACE BETWEEN PRODUCTS---------- -->
-   <a href="https://www.sparkfun.com/products/11375">
      <figure markdown>
        Hook-Up Wire - Assortment (Stranded, 22 AWG)
      </figure>
    </a>

    ---

    <a href="https://www.sparkfun.com/products/11375">
      <b>Hook-Up Wire - Assortment (Stranded, 22 AWG)</b>
      <br />
      PRT-11375
    </a>
<!-- ----------WHITE SPACE BETWEEN PRODUCTS---------- -->
-   <a href="https://www.sparkfun.com/products/22263">
      <figure markdown>
        Wire Stripper - 20-30 AWG Solid (22-32 AWG Stranded)
      </figure>
    </a>

    ---

    <a href="https://www.sparkfun.com/products/22263">
      <b>Wire Stripper - 20-30 AWG Solid (22-32 AWG Stranded)</b>
      <br />
      TOL-22263
    </a>
<!-- ----------WHITE SPACE BETWEEN PRODUCTS---------- -->
-   <a href="https://www.sparkfun.com/products/14782">
      <figure markdown>
        Flush Cutters - Xcelite
      </figure>
    </a>

    ---

    <a href="https://www.sparkfun.com/products/14782">
      <b>Flush Cutters - Xcelite</b>
      <br />
      TOL-14782
    </a>
<!-- ----------WHITE SPACE BETWEEN PRODUCTS---------- -->
</div>

### Prototyping Accessories &nbsp;_(Optional)_

As listed earlier, we recommend using the 4-pin JST-GHR-04V cable to connect directly to the IoT RedBoard - ESP32's female header pins. However, you could also use IC hooks for a temporary connection depending on your setup and what you have available. For those that prefer to the 0.1" spaced PTH, you will want to solder header pins for a secure connection.

* [Breadboard - Self-Adhesive (White) [PRT-12002]](https://www.sparkfun.com/products/12002)
* [IC Hook with Pigtail [CAB-09741]](https://www.sparkfun.com/products/9741)
* [Break Away Headers - Straight [PRT-00116]](https://www.sparkfun.com/products/116)
* [Female Headers [PRT-00115]](https://www.sparkfun.com/products/115)
* [Jumper Wires Premium 6" M/M Pack of 10 [PRT-08431]](https://www.sparkfun.com/products/8431)

<div class="grid cards col-4" markdown>
<!-- ----------WHITE SPACE BETWEEN PRODUCTS---------- -->
-   <a href="https://www.sparkfun.com/products/12002">
      <figure markdown>
        Breadboard - Self-Adhesive (White)
      </figure>
    </a>

    ---

    <a href="https://www.sparkfun.com/products/12002">
      <b>Breadboard - Self-Adhesive (White)</b>
      <br />
      PRT-12002
    </a>
<!-- ----------WHITE SPACE BETWEEN PRODUCTS---------- -->
-   <a href="https://www.sparkfun.com/products/9741">
      <figure markdown>
        IC Hook with Pigtail
      </figure>
    </a>

    ---

    <a href="https://www.sparkfun.com/products/9741">
      <b>IC Hook with Pigtail</b>
      <br>
      CAB-09741
    </a>
<!-- ----------WHITE SPACE BETWEEN PRODUCTS---------- -->
-   <a href="https://www.sparkfun.com/products/116">
      <figure markdown>
        Break Away Headers - Straight
      </figure>
    </a>

    ---

    <a href="https://www.sparkfun.com/products/116">
      <b>Break Away Headers - Straight</b>
      <br />
      PRT-00116
    </a>
<!-- ----------WHITE SPACE BETWEEN PRODUCTS---------- -->
-   <a href="https://www.sparkfun.com/products/115">
      <figure markdown>
        Female Headers
      </figure>
    </a>

    ---

    <a href="https://www.sparkfun.com/products/115">
      <b>Female Headers</b>
      <br />
      PRT-00115
    </a>
<!-- ----------WHITE SPACE BETWEEN PRODUCTS---------- -->
-   <a href="https://www.sparkfun.com/products/8431">
      <figure markdown>
        Jumper Wires Premium 6
      <br />
      PRT-08431
    </a>
<!-- ----------WHITE SPACE BETWEEN PRODUCTS---------- -->
</div>

### Suggested Reading

If you aren’t familiar with the following concepts, we also recommend checking out a few of these tutorials before continuing.

<div class="grid cards col-4" markdown>
<!-- ----------WHITE SPACE BETWEEN GRID CARDS---------- -->
-   <a href="https://learn.sparkfun.com/tutorials/9">
      <figure markdown>
        GPS Basics
      </figure>
    </a>

    ---

    <a href="https://learn.sparkfun.com/tutorials/9">
      <b>GPS Basics</b>
    </a>
<!-- ----------WHITE SPACE BETWEEN GRID CARDS---------- -->
-   <a href="https://learn.sparkfun.com/tutorials/iot-redboard-esp32-development-board-hookup-guide">
      <figure markdown>
        IoT RedBoard ESP32 Development Board Hookup Guide
      </figure>
    </a>

    ---

    <a href="https://learn.sparkfun.com/tutorials/iot-redboard-esp32-development-board-hookup-guide">
      <b>IoT RedBoard ESP32 Development Board Hookup Guide</b>
    </a>
<!-- ----------WHITE SPACE BETWEEN GRID CARDS---------- -->
-   <a href="https://learn.sparkfun.com/tutorials/installing-arduino-ide">
      <figure markdown>
        Installing Arduino IDE
      </figure>
    </a>

    ---

    <a href="https://learn.sparkfun.com/tutorials/installing-arduino-ide">
      <b>Installing Arduino IDE</b>
    </a>
<!-- ----------WHITE SPACE BETWEEN GRID CARDS---------- -->
-   <a href="https://learn.sparkfun.com/tutorials/installing-board-definitions-in-the-arduino-ide">
      <figure markdown>
        Installing Board Definitions in the Arduino IDE
      </figure>
    </a>

    ---

    <a href="https://learn.sparkfun.com/tutorials/installing-board-definitions-in-the-arduino-ide">
      <b>Installing Board Definitions in the Arduino IDE</b>
    </a>
<!-- ----------WHITE SPACE BETWEEN GRID CARDS---------- -->
-   <a href="https://learn.sparkfun.com/tutorials/how-to-solder-through-hole-soldering">
      <figure markdown>
        How to Solder: Through-Hole Soldering
      </figure>
    </a>

    ---

    <a href="https://learn.sparkfun.com/tutorials/how-to-solder-through-hole-soldering">
      <b>How to Solder: Through-Hole Soldering</b>
    </a>
<!-- ----------WHITE SPACE BETWEEN GRID CARDS---------- -->
-   <a href="https://learn.sparkfun.com/tutorials/serial-communication">
      <figure markdown>
        Serial Communication
      </figure>
    </a>

    ---

    <a href="https://learn.sparkfun.com/tutorials/serial-communication">
      <b>Serial Communication</b>
    </a>
<!-- ----------WHITE SPACE BETWEEN GRID CARDS---------- -->
</div>

You may also be interested in the following blog posts on GNSS technologies.

<div class="grid cards col-4" markdown align="center">

-   <a href="https://www.sparkfun.com/news/4276">
	<figure markdown>
	Tutorial Thumbnail
	</figure>

	---

	**GPS vs GNSS**</a>

-   <a href="https://www.sparkfun.com/news/7138">
	<figure markdown>
	Tutorial Thumbnail
	</figure>

	---

	**What is Correction Data?**</a>

-   <a href="https://www.sparkfun.com/news/7533">
	<figure markdown>
	Tutorial Thumbnail
	</figure>

	---

	**Real-Time Kinematics Explained**</a>

</div>

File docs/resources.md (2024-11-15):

Now that you've successfully got your SparkFun TriBand GNSS RTK- Breakout - UM980 up and running, it's time to incorporate it into your own project! For more information, check out the resources below:

* [Schematic (PDF)](../assets/board_files/SparkFun_GNSS_UM980_Schematic_v11.pdf)
* [KiCad Files (ZIP)](../assets/board_files/SparkFun_GNSS_UM980_v11.zip)
* [3D Model (STEP)](../assets/3d_model/SparkFun_GNSS_UM980_3D_model.step)
* [Board Dimensions (PNG)](../assets/img/SparkFun_GNSS_UM980-User_Drawings.png)
* Unicore Communications UM980
    * [General Specifications (PDF)](../assets/component_documentation/RX UNICORE UM980 (04-23).pdf)
    * [Datasheet (PDF)](../assets/component_documentation/UM980_Datasheet.pdf)
    * [User Manual (PDF)](../assets/component_documentation/UM980_User Manual_EN_R1.1.pdf)
    * [Reference Commands Manual (PDF)](../assets/component_documentation/Unicore_Reference_Commands_Manual_For_N4_High_Precision_Products_V2_EN_R1_1.pdf)
    * [UPrecise V2.0 (EXE)](https://en.unicore.com/uploads/file/Tool/uprecise-v2-0.exe)
    * [UPrecise User Manual (PDF)](../assets/component_documentation/uprecise-user-manual-en-r2-0.pdf)
* [CH340 Drivers](https://learn.sparkfun.com/tutorials/how-to-install-ch340-drivers)
* [SparkFun RTK](https://www.sparkfun.com/rtk)
* [Arduino Library](https://github.com/sparkfun/SparkFun_Unicore_GNSS_Arduino_Library)
* [GitHub Hardware Repo](https://github.com/sparkfun/SparkFun_UM980_Triband_GNSS_RTK_Breakout)
* [SFE Product Showcase](https://www.youtube.com/watch?v=JRmVSYMMBFU)

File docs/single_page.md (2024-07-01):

---
hide:
  - navigation
  - toc
icon: fontawesome/solid/scroll
---

# Introduction
--8<-- "./docs/introduction.md"

# Hardware Overview
--8<-- "./docs/hardware_overview.md"

# Hardware Hookup
--8<-- "./docs/hardware_hookup.md"

# Installing the Arduino Library
--8<-- "./docs/arduino_library.md"

# Arduino Examples
--8<-- "./docs/arduino_examples.md"

# Installing UPrecise
--8<-- "./docs/uprecise.md"

# Firmware Update
--8<-- "./docs/firmware_update.md"

# Verification
--8<-- "./docs/verification.md"

# Troubleshooting
--8<-- "./docs/troubleshooting.md"

# Resources
--8<-- "./docs/resources.md"

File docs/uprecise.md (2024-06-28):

For users interested in a GUI to visualize the data or update firmware, there is the UPrecise Software. You can head over to [Unicore's UPrecise Download Page](https://en.unicore.com/products/uprecise.html). Or clicking on the button below to download UPrecise.

<div style="text-align: center"><a href="https://en.unicore.com/uploads/file/Tool/uprecise-v2-0.exe" class="md-button">Click Here to Download UPrecise V2.0 (EXE)</a></div>

!!! note
    For the latest software version, you may want to check the [Unicore's UPrecise Download Page](https://en.unicore.com/products/uprecise.html).

Once downloaded, select the executable and follow the prompts to install the software to your computer. Note that the software is currently only supported on Windows 7/8/10, 64-bit OS.

### Selecting a Language

After downloading and installing UPrecise, open the software up! There are two languages that are supported with the software. For the scope of this tutorial, we'll be using the software in English. Click on "CH" button to change the default language from Chinese to English.

<div style="text-align: center;">
  <table>
    <tr style="vertical-align:middle;">
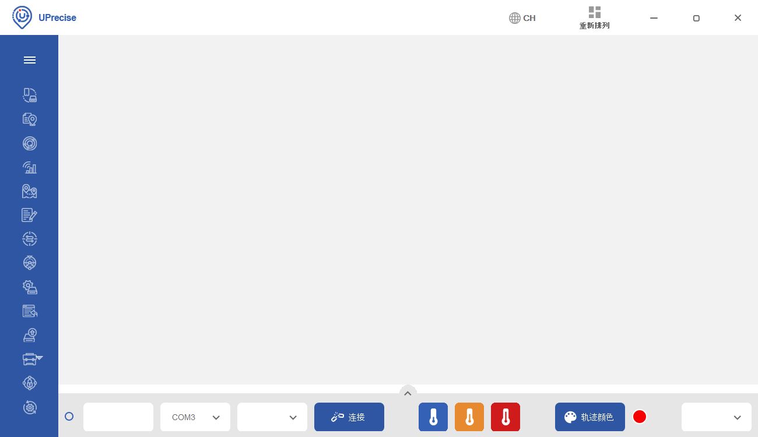
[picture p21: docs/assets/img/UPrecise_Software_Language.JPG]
UPrecise Software Open to Default Language, Chinese
     <td style="text-align: center; vertical-align: middle;"></td>
    </tr>
  </table>
</div>

For users with UPrecise V2.0, you will be prompted with a new window indicating that you will need reboot the software for the changes to take effect. Select the button on the left to reboot the software.

<div style="text-align: center;">
  <table>
    <tr style="vertical-align:middle;">
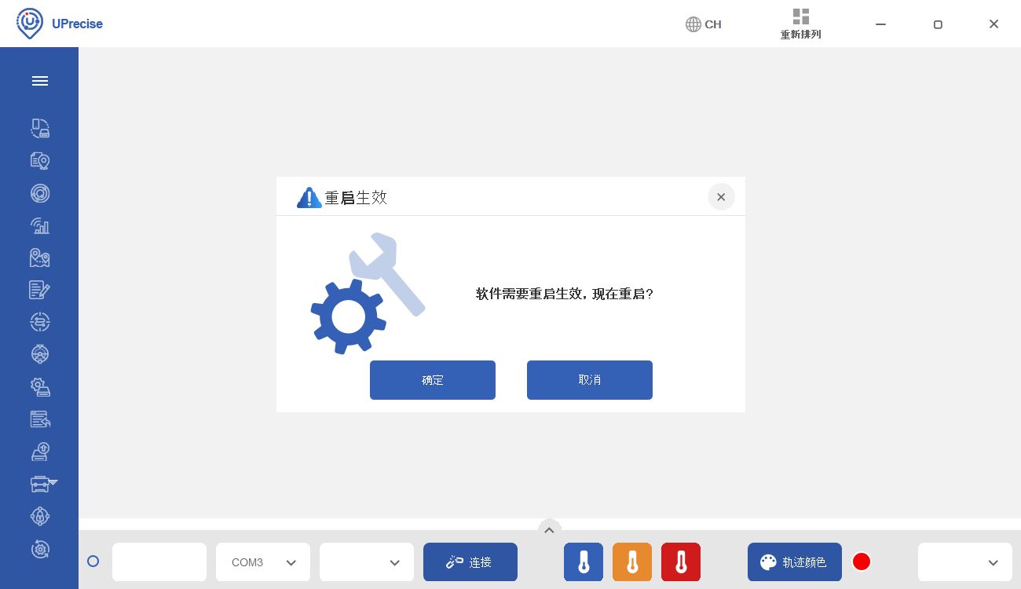
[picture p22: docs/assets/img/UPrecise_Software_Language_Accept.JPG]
UPrecise Software Reboot, Select OK
     <td style="text-align: center; vertical-align: middle;"></td>
    </tr>
  </table>
</div>

The language will switch to English similar to the image below.

<div style="text-align: center;">
  <table>
    <tr style="vertical-align:middle;">
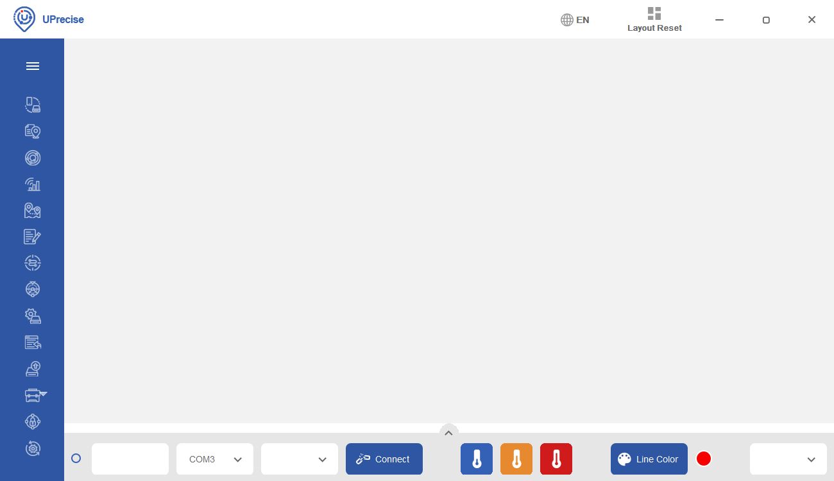
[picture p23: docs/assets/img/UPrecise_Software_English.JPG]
UPrecise Software in English
     <td style="text-align: center; vertical-align: middle;"></td>
    </tr>
  </table>
</div>

### Connecting the UM980 Breakout Board to a Computer

We will assume that you have a triband multiband antenna connected to the UM980's breakout board and USB cable connected to your computer. Select the COM port that the CH340 enumerated to. There is no need to make a selection in the other two drop down menus by the COM port since the software automatically determines the receiver and baud rate. In this case, it was **COM17**. You may need to [open your device manager to determine which COM port the CH340 enumerated to](https://learn.sparkfun.com/tutorials/how-to-install-ch340-drivers#windows-710).

<div style="text-align: center;">
  <table>
    <tr style="vertical-align:middle;">
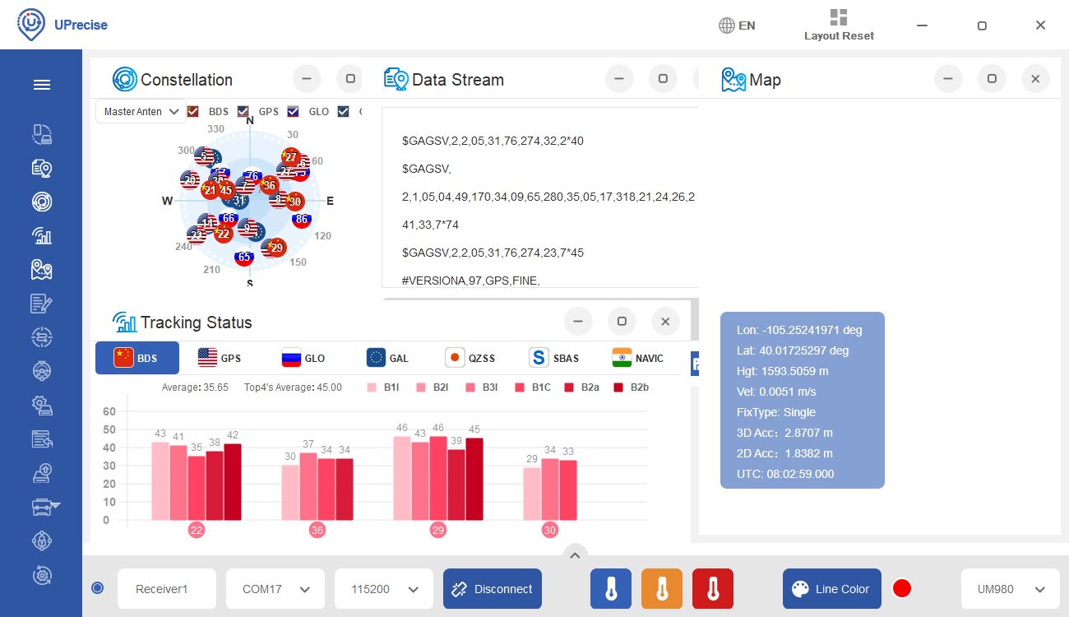
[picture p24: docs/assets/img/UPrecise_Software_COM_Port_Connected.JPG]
UPrecise Software: COM Port Connected
     <td style="text-align: center; vertical-align: middle;"></td>
    </tr>
  </table>
</div>

Once connected, try exploring the features available on the software as the UM980 sends data to your COM port. You can also check out the UPrecise user manual for more information on the software:

<div style="text-align: center"><a href="../assets/component_documentation/uprecise-user-manual-en-r2-0.pdf" class="md-button">UPrecise User Manual R2.0 - English (PDF)</a></div>

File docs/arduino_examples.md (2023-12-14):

Now that we have our library and board add-on installed, we can get started experimenting with the breakout board. For the scope of this tutorial, we will go over the examples from the Arduino Library. From there, we will be able to build our own custom code to integrate the development board into a project.

### Example 1: Position, Velocity, and Time

In this example, we will query a UM980's UART2 port for its position, velocity, and time data.

From the menu, select the following: **File** > **Examples** > **SparkFun UM980 Triband RTK GNSS Arduino Library** > **Example1_PositionVelocityTime** . If you have not already, select your Board (in this case the **SparkFun ESP32 IoT RedBoard**), and associated COM port. Then hit the upload button. After uploading the code, open the [Serial Monitor](https://learn.sparkfun.com/tutorials/terminal-basics/arduino-serial-monitor-windows-mac-linux) or terminal emulator of your choice with a baud rate set to **115200**.

Give it a moment to check the satellites in view. You will be able to see your position, velocity, date, time, and the number of satellites in view.

<div style="text-align: center;">
  <table>
    <tr style="vertical-align:middle;">
     <td style="text-align: center; vertical-align: middle;"><a href="../assets/img/Arduino_Output_Ex_1_ESP32_Triband_GNSS_RTK_UM980.JPG">Arduino Output - UM980 Example 1</a></td>
    </tr>
  </table>
</div>

### Example 2: Direct Connect

In this example, characters coming from the UM980's UART2 port are echoed and send characters to the UM980. This allows a user to directly enter command strings into the UM980 while still connected to the Arduino. This is good for viewing the raw output from a given command.

From the menu, select the following: **File** > **Examples** > **SparkFun UM980 Triband RTK GNSS Arduino Library** > **Example2_DirectConnect** . If you have not already, select your Board (in this case the **SparkFun ESP32 IoT RedBoard**), and associated COM port. Then hit the upload button. After uploading the code, open the [Serial Monitor](https://learn.sparkfun.com/tutorials/terminal-basics/arduino-serial-monitor-windows-mac-linux) or terminal emulator of your choice with a baud rate set to **115200**. For this example, make sure to have **both NL & *CR** turned on.

Type <kbd>CONFIG</kbd> and send the command through the serial terminal. You should receive a response with the current UM980 configuration. Make sure to check out the UM980's Reference Commands Manual linked in the [Resources for more commands](../resources).

<div style="text-align: center;">
  <table>
    <tr style="vertical-align:middle;">
     <td style="text-align: center; vertical-align: middle;"><a href="../assets/img/Arduino_Output_Ex_2_ESP32_Triband_GNSS_RTK_UM980.JPG">Arduino Output - UM980 Example 2</a></td>
    </tr>
  </table>
</div>

### Example 3: ECEF and Stats

This example will query the UM980's UART2 port for the signal quality and fix type.

From the menu, select the following: **File** > **Examples** > **SparkFun UM980 Triband RTK GNSS Arduino Library** > **Example3_ECEFandStats** . If you have not already, select your Board (in this case the **SparkFun ESP32 IoT RedBoard**), and associated COM port. Then hit the upload button. After uploading the code, open the [Serial Monitor](https://learn.sparkfun.com/tutorials/terminal-basics/arduino-serial-monitor-windows-mac-linux) or terminal emulator of your choice with a baud rate set to **115200**.

The output will be similar to example 1 with additional information.

<div style="text-align: center;">
  <table>
    <tr style="vertical-align:middle;">
     <td style="text-align: center; vertical-align: middle;"><a href="../assets/img/Arduino_Output_Ex_3_ESP32_Triband_GNSS_RTK_UM980.JPG">Arduino Output - UM980 Example 3</a></td>
    </tr>
  </table>
</div>

### Example 4: Enable NMEA at 5Hz

This example shows how to enable various NMEA sentences at different rates on different ports at 5Hz.

From the menu, select the following: **File** > **Examples** > **SparkFun UM980 Triband RTK GNSS Arduino Library** > **Example4_EnableNMEA_5Hz** .  If you have not already, select your Board (in this case the **SparkFun ESP32 IoT RedBoard**), and associated COM port. Then hit the upload button. After uploading the code, open the [Serial Monitor](https://learn.sparkfun.com/tutorials/terminal-basics/arduino-serial-monitor-windows-mac-linux) or terminal emulator of your choice with a baud rate set to **115200**.

The output will begin outputting NEMA sentences.

<div style="text-align: center;">
  <table>
    <tr style="vertical-align:middle;">
     <td style="text-align: center; vertical-align: middle;"><a href="../assets/img/Arduino_Output_Ex_4_ESP32_Triband_GNSS_RTK_UM980.JPG">Arduino Output - UM980 Example 4</a></td>
    </tr>
  </table>
</div>

### Example 5: Enable RTCM

This example shows how to configure the UM980 into base mode using specified coordinates.

From the menu, select the following: **File** > **Examples** > **SparkFun UM980 Triband RTK GNSS Arduino Library** > **Example5_EnableRTCM** .  If you have not already, select your Board (in this case the **SparkFun ESP32 IoT RedBoard**), and associated COM port. Then hit the upload button. After uploading the code, open the [Serial Monitor](https://learn.sparkfun.com/tutorials/terminal-basics/arduino-serial-monitor-windows-mac-linux) or terminal emulator of your choice with a baud rate set to **115200**.

Once open, the example will begin outputting the RTCM data. The Serial Terminal will output random characters due to the RTCM being in binary. This data will be interpreted by other high precision RTK GNSS modules.

<div style="text-align: center;">
  <table>
    <tr style="vertical-align:middle;">
     <td style="text-align: center; vertical-align: middle;"><a href="../assets/img/Arduino_Output_Ex_5_ESP32_Triband_GNSS_RTK_UM980.JPG">Arduino Output - UM980 Example 5</a></td>
    </tr>
  </table>
</div>

### Example 6: Average Base

This example shows how to put the UM980 into a Base mode configuration using the average of positional fixes obtained over a 60 second period. We also turn on RTCM messages.

From the menu, select the following: **File** > **Examples** > **SparkFun UM980 Triband RTK GNSS Arduino Library** > **Example6_AverageBase** .  If you have not already, select your Board (in this case the **SparkFun ESP32 IoT RedBoard**), and associated COM port. Then hit the upload button. After uploading the code, open the [Serial Monitor](https://learn.sparkfun.com/tutorials/terminal-basics/arduino-serial-monitor-windows-mac-linux) or terminal emulator of your choice with a baud rate set to **115200**.

Once open, the example will begin outputting certain NMEA sentences and RTCM messages.

<div style="text-align: center;">
  <table>
    <tr style="vertical-align:middle;">
     <td style="text-align: center; vertical-align: middle;"><a href="../assets/img/Arduino_Output_Ex_6_ESP32_Triband_GNSS_RTK_UM980.JPG">Arduino Output - UM980 Example 6</a></td>
    </tr>
  </table>
</div>

### Example 7: Fixed Base

This example shows how to put the UM980 into a Base mode configuration using specified coordinates.

From the menu, select the following: **File** > **Examples** > **SparkFun UM980 Triband RTK GNSS Arduino Library** > **Example7_FixedBase** .  If you have not already, select your Board (in this case the **SparkFun ESP32 IoT RedBoard**), and associated COM port. Then hit the upload button. After uploading the code, open the [Serial Monitor](https://learn.sparkfun.com/tutorials/terminal-basics/arduino-serial-monitor-windows-mac-linux) or terminal emulator of your choice with a baud rate set to **115200**.

Once open, the example will begin outputting certain NMEA sentences and RTCM messages.

<div style="text-align: center;">
  <table>
    <tr style="vertical-align:middle;">
     <td style="text-align: center; vertical-align: middle;"><a href="../assets/img/Arduino_Output_Ex_7_ESP32_Triband_GNSS_RTK_UM980.JPG">Arduino Output - UM980 Example 7</a></td>
    </tr>
  </table>
</div>

### Example 8: Set Constellations

This example enables/disables various constellations to be included in position calculations for GPS, GLO, BDS, GAL, and QZSS.

From the menu, select the following: **File** > **Examples** > **SparkFun UM980 Triband RTK GNSS Arduino Library** > **Example8_SetConstellations** .  If you have not already, select your Board (in this case the **SparkFun ESP32 IoT RedBoard**), and associated COM port. Then hit the upload button. After uploading the code, open the [Serial Monitor](https://learn.sparkfun.com/tutorials/terminal-basics/arduino-serial-monitor-windows-mac-linux) or terminal emulator of your choice with a baud rate set to **115200**.

Once open, the output will respond with a message indicating if the GPS was enabled and the configuration is complete.

<div style="text-align: center;">
  <table>
    <tr style="vertical-align:middle;">
     <td style="text-align: center; vertical-align: middle;"><a href="../assets/img/Arduino_Output_Ex_8_ESP32_Triband_GNSS_RTK_UM980.JPG">Arduino Output - UM980 Example 8</a></td>
    </tr>
  </table>
</div>

### Example 9: Signal Elevation

This example shows how set the Elevation Angle and minimum CN0 value required from a satellite to be included in the position calculation.

From the menu, select the following: **File** > **Examples** > **SparkFun UM980 Triband RTK GNSS Arduino Library** > **Example9_SignalEleveation** .  If you have not already, select your Board (in this case the **SparkFun ESP32 IoT RedBoard**), and associated COM port. Then hit the upload button. After uploading the code, open the [Serial Monitor](https://learn.sparkfun.com/tutorials/terminal-basics/arduino-serial-monitor-windows-mac-linux) or terminal emulator of your choice with a baud rate set to **115200**.

Once open, the output will notify you when the UM980 is configured.

<div style="text-align: center;">
  <table>
    <tr style="vertical-align:middle;">
     <td style="text-align: center; vertical-align: middle;"><a href="../assets/img/Arduino_Output_Ex_9_ESP32_Triband_GNSS_RTK_UM980.JPG">Arduino Output - UM980 Example 9</a></td>
    </tr>
  </table>
</div>

### Example 10: Set Rover Mode

This example shows how set the station mode to Survey, UAV, or Automotive.

From the menu, select the following: **File** > **Examples** > **SparkFun UM980 Triband RTK GNSS Arduino Library** > **Example10_SetRoverMode**.  If you have not already, select your Board (in this case the **SparkFun ESP32 IoT RedBoard**), and associated COM port. Then hit the upload button. After uploading the code, open the [Serial Monitor](https://learn.sparkfun.com/tutorials/terminal-basics/arduino-serial-monitor-windows-mac-linux) or terminal emulator of your choice with a baud rate set to **115200**.

Once open, the output will notify you when the UM980 is configured. If you need to configure the device for a different mode, you will just need to use a [single line comment (`//`)](https://www.arduino.cc/reference/en/language/structure/further-syntax/singlelinecomment/) to adjust the code.

<div style="text-align: center;">
  <table>
    <tr style="vertical-align:middle;">
     <td style="text-align: center; vertical-align: middle;"><a href="../assets/img/Arduino_Output_Ex_9_ESP32_Triband_GNSS_RTK_UM980.JPG">Arduino Output - UM980 Example 9</a></td>
    </tr>
  </table>
</div>

### Example 11: USB NMEA

This sketch turns on all the major NMEA sentences at 2Hz and prints the incoming serial out to the Serial port. This is useful for viewing the GNSS data in a program like u-center (u-blox's software) or UPrecise (Unicore's software).

From the menu, select the following: **File** > **Examples** > **SparkFun UM980 Triband RTK GNSS Arduino Library** > **Example11_UsbNMEA** .  If you have not already, select your Board (in this case the **SparkFun ESP32 IoT RedBoard**), and associated COM port. Then hit the upload button. After uploading the code, open the [Serial Monitor](https://learn.sparkfun.com/tutorials/terminal-basics/arduino-serial-monitor-windows-mac-linux) or terminal emulator of your choice with a baud rate set to **115200**.

Once open, the output will notify you when the UM980 is configured.

<div style="text-align: center;">
  <table>
    <tr style="vertical-align:middle;">
     <td style="text-align: center; vertical-align: middle;"><a href="../assets/img/Arduino_Output_Ex_11_ESP32_Triband_GNSS_RTK_UM980.JPG">Arduino Output - UM980 Example 11</a></td>
    </tr>
  </table>
</div>

Disconnect the UM980 from the IoT RedBoard - ESP32. Then disconnect the USB cable from the IoT RedBoard - ESP32. Connect the USB cable between the UM980 and your computer. Open a terminal emulator set at **115200** baud. Once connected, you should begin seeing NMEA sentences through the USB port.

<div style="text-align: center;">
  <table>
    <tr style="vertical-align:middle;">
     <td style="text-align: center; vertical-align: middle;"><a href="../assets/img/USB_Output_Ex_11_Triband_GNSS_RTK_UM980.JPG">UM980 USB NMEA Output</a></td>
    </tr>
  </table>
</div>

Of course, you can also view the data through a GUI such as the u-center (u-blox's software) or UPrecise (Unicore's software) as well.

### Example 12: Factory Reset

This example shows how set the UM980 back to factory defaults.

From the menu, select the following: **File** > **Examples** > **SparkFun UM980 Triband RTK GNSS Arduino Library** > **Example12_FactoryReset** .  If you have not already, select your Board (in this case the **SparkFun ESP32 IoT RedBoard**), and associated COM port. Then hit the upload button. After uploading the code, open the [Serial Monitor](https://learn.sparkfun.com/tutorials/terminal-basics/arduino-serial-monitor-windows-mac-linux) or terminal emulator of your choice with a baud rate set to **115200**.

Once open, the output will notify you when the UM980 is ready to be configured. Send a character through the [Serial Monitor](https://learn.sparkfun.com/tutorials/terminal-basics/arduino-serial-monitor-windows-mac-linux) to factory reset the UM980. The code will then begin outputting the position, velocity, date, time, and satellites as shown in example 1. Give it a moment to check the satellites in view before getting valid data.

<div style="text-align: center;">
  <table>
    <tr style="vertical-align:middle;">
     <td style="text-align: center; vertical-align: middle;"><a href="../assets/img/Arduino_Output_Ex_12_ESP32_Triband_GNSS_RTK_UM980.JPG">Arduino Output - UM980 Example 12</a></td>
    </tr>
  </table>
</div>

### Example 13: Send Command

While the SparkFun UM980 Arduino library covers most of the features in the UM980, there may be a special command that is needed but not supported. This sketch shows how to send commands directly to the UM980.

From the menu, select the following: **File** > **Examples** > **SparkFun UM980 Triband RTK GNSS Arduino Library** > **Example13_SendCommand* .  If you have not already, select your Board (in this case the **SparkFun ESP32 IoT RedBoard**), and associated COM port. Then hit the upload button. After uploading the code, open the [Serial Monitor](https://learn.sparkfun.com/tutorials/terminal-basics/arduino-serial-monitor-windows-mac-linux) or terminal emulator of your choice with a baud rate set to **115200**.

Once open, there's not too much in the output. Try adjusting the ASCII command within the `myGNSS.sendCommand()` to send a different special command. For more information, try looking at the [Reference Commands Manual in the Resources](../resources).

<div style="text-align: center;">
  <table>
    <tr style="vertical-align:middle;">
     <td style="text-align: center; vertical-align: middle;"><a href="../assets/img/Arduino_Output_Ex_13_ESP32_Triband_GNSS_RTK_UM980.JPG">Arduino Output - UM980 Example 13</a></td>
    </tr>
  </table>
</div>

### Example 14: Set PPS

The example shows how to configure the PPS signal's width, frequency, and polarity.  

From the menu, select the following: **File** > **Examples** > **SparkFun UM980 Triband RTK GNSS Arduino Library** > **Example14_SetPPS** .  If you have not already, select your Board (in this case the **SparkFun ESP32 IoT RedBoard**), and associated COM port. Then hit the upload button. After uploading the code, open the [Serial Monitor](https://learn.sparkfun.com/tutorials/terminal-basics/arduino-serial-monitor-windows-mac-linux) or terminal emulator of your choice with a baud rate set to **115200**.

Once open, the output just tells you the rate that the PPS is blinking at. If you look at the PPS LED on the UM980, the LED will blink at the rate that was set.

<div style="text-align: center;">
  <table>
    <tr style="vertical-align:middle;">
     <td style="text-align: center; vertical-align: middle;"><a href="../assets/img/Arduino_Output_Ex_14_ESP32_Triband_GNSS_RTK_UM980.JPG">Arduino Output - UM980 Example 14</a></td>
    </tr>
  </table>
</div>

### Example 15: Query Device

This example shows how to send the 'CONFIG' command to get a clear text response that the user can parse to see which settings are set. In this case, we will get the current configuration, version, mode, and mask from the UM980.

From the menu, select the following: **File** > **Examples** > **SparkFun UM980 Triband RTK GNSS Arduino Library** > **Example15_QueryDevice** .  If you have not already, select your Board (in this case the **SparkFun ESP32 IoT RedBoard**), and associated COM port. Then hit the upload button. After uploading the code, open the [Serial Monitor](https://learn.sparkfun.com/tutorials/terminal-basics/arduino-serial-monitor-windows-mac-linux) or terminal emulator of your choice with a baud rate set to **115200**.

<div style="text-align: center;">
  <table>
    <tr style="vertical-align:middle;">
     <td style="text-align: center; vertical-align: middle;"><a href="../assets/img/Arduino_Output_Ex_15_ESP32_Triband_GNSS_RTK_UM980.JPG">Arduino Output - UM980 Example 15</a></td>
    </tr>
  </table>
</div>

### Example 16: Poll for Valid RTCM Messages

The documentation for the UM980 does not explicitly state which RTCM messages are supported but by sending the enable command to the module we can insinuate which are supported. This sketch sends the 'RTCMxxxx' command and looks for an OK.

From the menu, select the following: **File** > **Examples** > **SparkFun UM980 Triband RTK GNSS Arduino Library** > **Example15_PollForValidRTCMMessages** .  If you have not already, select your Board (in this case the **SparkFun ESP32 IoT RedBoard**), and associated COM port. Then hit the upload button. After uploading the code, open the [Serial Monitor](https://learn.sparkfun.com/tutorials/terminal-basics/arduino-serial-monitor-windows-mac-linux) or terminal emulator of your choice with a baud rate set to **115200**.

Once open, the output will notify you of the RTCM messages that are supported. As of the writing of this tutorial, there are 55 RTCM messages that are supported!

<div style="text-align: center;">
  <table>
    <tr style="vertical-align:middle;">
     <td style="text-align: center; vertical-align: middle;"><a href="../assets/img/Arduino_Output_Ex_16_ESP32_Triband_GNSS_RTK_UM980.JPG">Arduino Output - UM980 Example 16</a></td>
    </tr>
  </table>
</div>

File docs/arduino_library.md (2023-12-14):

!!! arduino
    This example assumes you are using the latest version of the Arduino IDE on your desktop. If this is your first time using the Arduino IDE, library, or board add-on, please review the following tutorials.

    - [Installing the Arduino IDE](https://learn.sparkfun.com/tutorials/installing-arduino-ide)
    - [Installing Board Definitions in the Arduino IDE](https://learn.sparkfun.com/tutorials/installing-board-definitions-in-the-arduino-ide)
    - [Installing an Arduino Library](https://learn.sparkfun.com/tutorials/installing-an-arduino-library)

SparkFun has written a library to work with the Unicore UM980 module. You can obtain this library through the Arduino Library Manager by searching for "**SparkFun Unicore GNSS**". Find the one written by SparkFun Electronics and install the latest version. Users who prefer to manually install the library can get it from the  [GitHub Repository](https://github.com/sparkfun/SparkFun_Unicore_GNSS_Arduino_Library/) or download the .ZIP by clicking the button below:

<div style="text-align: center"><a href="https://github.com/sparkfun/SparkFun_Unicore_GNSS_Arduino_Library/archive/refs/heads/main.zip" class="md-button">SparkFun Unicore GNSS Arduino Library (ZIP)</a></div>

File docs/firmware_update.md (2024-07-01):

!!! note
     The following instructions were taken from the UPrecise User Manual: 2.2.11 Receiver Upgrade. For more information about how to use UPrecise software, make sure to check out the user manual.

!!! note
    At the time of writing, UPrecise Version 2.0 was used. Note that the GUI appearance and features may change upon future releases.

You can update your firmware (they call this a firmware upgrade in the manual) using Unicore's UPrecise software. Make sure to check [Unicore's UM980 product page](https://en.unicorecomm.com/products/detail/26), [download center](https://en.unicore.com/download-center/), or contact Unicore Communications for any firmware releases.

We'll assume that you have the firmware downloaded at this point and connected to the UM980. With UPrecise open, click on the menu with the triple bar (**&equiv;**) near the upper left of the window to expand the menu.

<div style="text-align: center;">
  <table>
    <tr style="vertical-align:middle;">
     <td style="text-align: center; vertical-align: middle;"><a href="../assets/img/UPrecise_Software_COM_Port_Connected.JPG">UPrecise Software: COM Port Connected</a></td>
    </tr>
  </table>
</div>

The menu should expand with text next to each icon.

<div style="text-align: center;">
  <table>
    <tr style="vertical-align:middle;">
     <td style="text-align: center; vertical-align: middle;"><a href="../assets/img/UPrecise_Software_Expand_Menu_Connected.JPG">UPrecise Software: Menu Expanded</a></td>
    </tr>
  </table>
</div>

Click on the **Receiver Upgrade** button. The following window should open up.

<div style="text-align: center;">
  <table>
    <tr style="vertical-align:middle;">
     <td style="text-align: center; vertical-align: middle;"><a href="../assets/img/UPrecise_Software_Receiver_Upgrade.JPG">UPrecise Software: Receiver Upgrade</a></td>
    </tr>
  </table>
</div>

Click the **Select upgrade file** button. Head to the folder where you downloaded the firmware and select the file. The extension should be a  **&#42;pkg** file.  In this case, there was a copy of the firmware in the [GitHub SparkFun UM980 Triband GNSS RTK Breakout Repo](https://github.com/sparkfun/SparkFun_UM980_Triband_GNSS_RTK_Breakout/tree/main/Firmware) named "_UM980_R4.10Build11833.pkg_". Older firmware versions were moved to the **Old Firmware** folder.

<div style="text-align: center;">
  <table>
    <tr style="vertical-align:middle;">
     <td style="text-align: center; vertical-align: middle;"><a href="../assets/img/UPrecise_Software_Select_File.JPG">UPrecise Software: Select File</a></td>
    </tr>
  </table>
</div>

<!--

NO OPTION FOR DOUBLE BACKUP...

If necessary, you can select the "Double backup" checkbox. Once the module has finished updating, the main partition makes a backup in the backup partition. If the main partition fails, the module will boot from the backup partition.

<div style="text-align: center;">
  <table>
    <tr style="vertical-align:middle;">
     <td style="text-align: center; vertical-align: middle;"><a href="../assets/img/"><img src="../assets/img/" width="600px" height="600px" alt=""></a></td>
    </tr>
  </table>
</div>

-->

Select the GNSS receiver that will be receiving the firmware update. In this case it was **Receiver1**. While we are at it, select either the "**Soft reset**" or "**Hard reset**". While updating, the module will need to be reset and this selection will determine the reset method. Let's select the "**Soft Reset**" and have UPrecise reset the module.

<div style="text-align: center;">
  <table>
    <tr style="vertical-align:middle;">
     <td style="text-align: center; vertical-align: middle;"><a href="../assets/img/UPrecise_Software_Select_Receiver_Reset_Method.JPG">UPrecise Software: Select Receiver and Reset Method</a></td>
    </tr>
  </table>
</div>

When ready, hit the "Start" button!

<div style="text-align: center;">
  <table>
    <tr style="vertical-align:middle;">
     <td style="text-align: center; vertical-align: middle;"><a href="../assets/img/UPrecise_Software_Firmware_Updating_Soft_Reset.JPG">UPrecise Software: Firmware Update in Progress with Soft Reset Method</a></td>
    </tr>
  </table>
</div>

!!! warning
    Make sure to pay attention to the progress bar! You'll want to avoid any interruptions while the firmware is updating as this will cause the upgrade to fail.

!!! note
    If you have issues updating the software with the reset method chosen, try exiting the Receiver Upgrade menu by hitting the "x" button. Then disconnect and reconnect the module by selecting the "Connect" button. You will then need to open the **Receiver Upgrade** window again before hitting the "Start" button.

Once the firmware has been updated, you will notice that the progress bar is at 100% and a message indicating that the firmware upgrade succeeded and finished. You can exit out of the window by clicking on the "**x**" button.

<div style="text-align: center;">
  <table>
    <tr style="vertical-align:middle;">
     <td style="text-align: center; vertical-align: middle;"><a href="../assets/img/UPrecise_Software_Receiver_Upgrade_Finished.JPG">UPrecise Software: Receiver Upgrade Finished</a></td>
    </tr>
  </table>
</div>

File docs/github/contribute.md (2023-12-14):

# Contribute: Help Fix our Mistake!
Spot something wrong? Feel free to contribute our open-source design and documentation. 

## Improve our Documentation
All of this documentation can be modified by you! Please help us make it better.

* These pages are contained in the [`docs` folder of the SparkFun Triband GNSS RTK Breakout - UM980 repository](https://github.com/sparkfun/SparkFun_UM980_Triband_GNSS_RTK_Breakout/tree/main/docs).

### Submit a Correction
1. Fork this repo
2. Add your corrections or improvements to the markdown file
3. File a pull request with your changes, and enjoy making the ~~words~~ ~~worlds~~ world a better place.
    * Once received, the documentation specialist will automatically be notified.
    * We will review your suggested improvements to make sure they are correct and fit within our documentation standards.

## Improve our Hardware Design
All of our designs are open-source! Please help us make it better.

* Our board design files are contained in the [`Hardware` folder of the SparkFun Triband GNSS RTK Breakout repository](https://github.com/sparkfun/SparkFun_UM980_Triband_GNSS_RTK_Breakout/tree/main/Hardware).

### Submit a Design Improvement
1. Fork this repo
2. Add your design improvements
3. File a pull request with your changes, and enjoy making the ~~words~~ ~~worlds~~ world a better place.
    * Once received, the engineer in charge of the original design will automatically be notified.
    * We will review your suggested improvements, if they are within our board design standards and meet our product design requirements, we will flag these changes for our next board revision. *(Please note, that even if your suggestion is accepted, these changes may not be immediate. We may have to cycle through our current product inventory first.)*

## Contributors
Let's provided some recognition to the contributors for this project!

GitHub Contributors Image
<br>


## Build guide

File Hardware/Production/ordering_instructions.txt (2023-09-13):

Ordering Instructions:
Panel dimensions: 121.90 x 115.80 mm.
Controlled Impedance: JLC7628
Material: TG155
Solder Mask: Red
Silkscreen: White
Layers: 4
Finish: ENIG
Thickness: 1.6mm
Copper weight: 1oz
Minimum track width: 0.18mm (7.00mil)
Minimum via drill: 0.30mm (12.00mil)
No Clean Process

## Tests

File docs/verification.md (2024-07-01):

Now that we have successfully flashed the firmware, let's verify the version number. In the serial terminal, send the command `VERSIONA`. The UM980 will respond by providing the firmware version and authorization date. Look for the part of the message after the model number (i.e. "UM980"). This should match the build number from **&#42;pkg** file name.

<div style="text-align: center;">
  <table>
    <tr style="vertical-align:middle;">
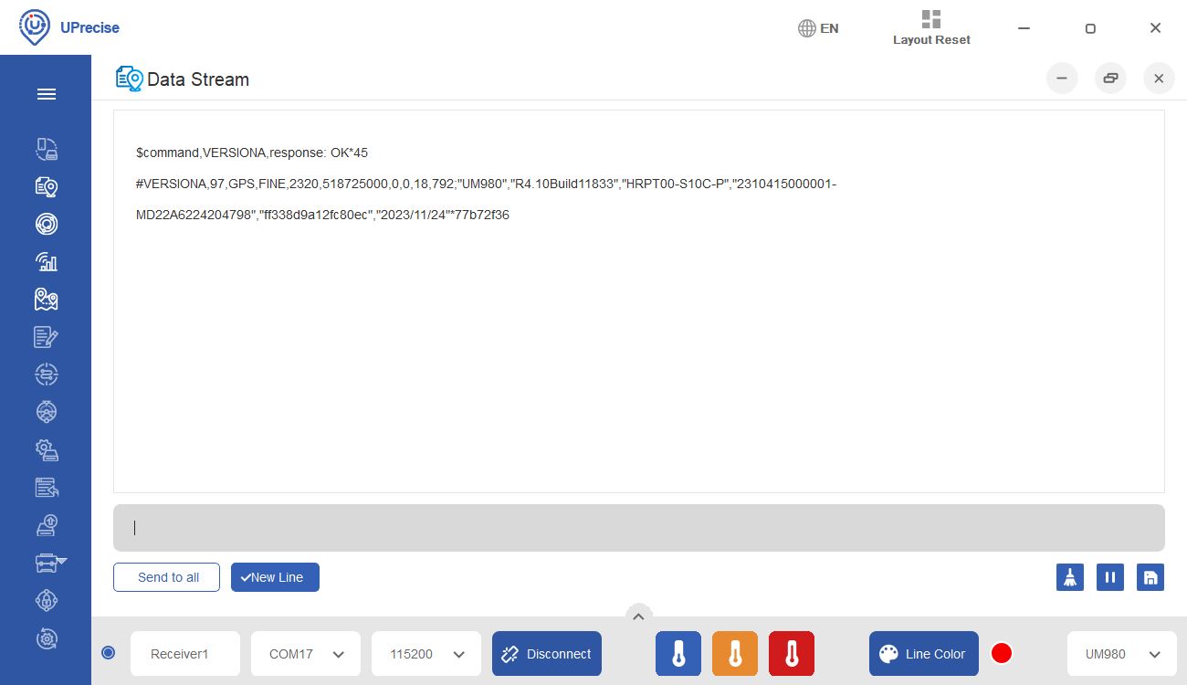
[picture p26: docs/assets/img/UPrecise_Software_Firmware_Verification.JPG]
UPrecise Software: Sending Command VERSIONA
     <td style="text-align: center; vertical-align: middle;"></td>
    </tr>
  </table>
</div>

!!! note
    Sending the command `VERSIONA` is one method of verifying the version number on the UM980. You can use the [Arduino example code](https://docs.sparkfun.com/SparkFun_UM980_Triband_GNSS_RTK_Breakout/arduino_examples/#example-15-query-device) to verify the version number on the UM980 breakout board.

    <div style="text-align: center;">
      <table>
        <tr style="vertical-align:middle;">
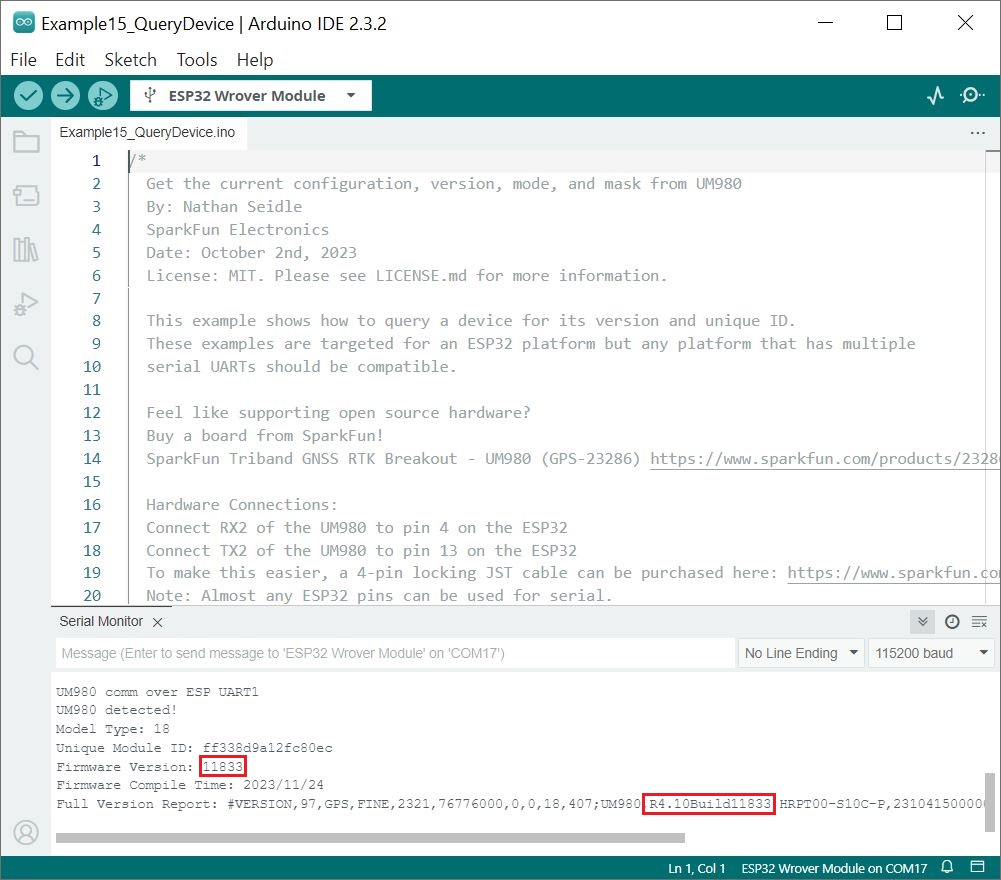
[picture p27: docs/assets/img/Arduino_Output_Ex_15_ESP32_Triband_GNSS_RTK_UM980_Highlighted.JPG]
UM980 Firmware Output with Arduino
         <td style="text-align: center; vertical-align: middle;"></td>
        </tr>
      </table>
    </div>

Try viewing the UM980 output through the UPrecise software. Not seeing any satellites in the GUI or output in the serial terminal? Try adjusting the configuration to output every second. From the menu, head to the following to configure the messages: **Receiver Configurations** > **Message configuration**. In this case, we selected the following: **GGA**, **GSA**, **GSV**, **RMC**, **GST**. Feel free to select more depending on your application.

<div style="text-align: center;">
  <table>
    <tr style="vertical-align:middle;">
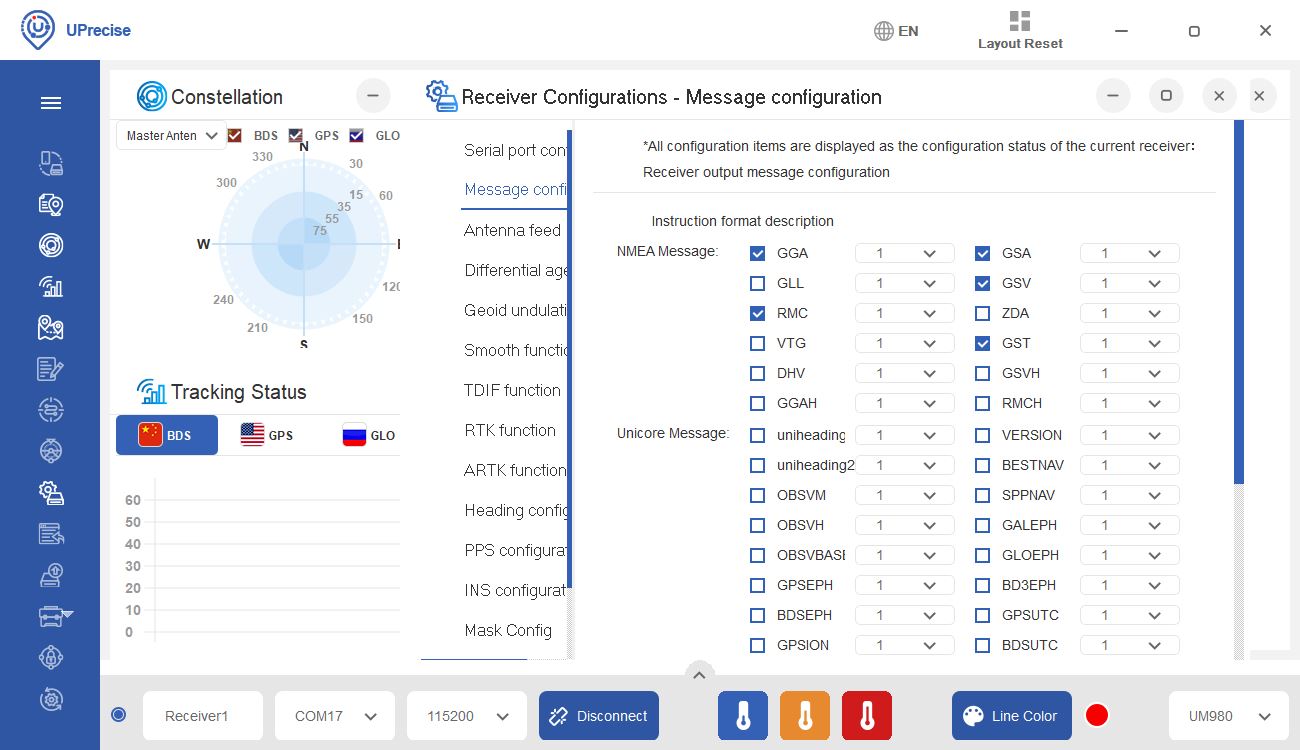
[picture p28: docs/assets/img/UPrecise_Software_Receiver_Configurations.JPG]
UPrecise Software: Receiver Configurations - Message configuration
     <td style="text-align: center; vertical-align: middle;"></td>
    </tr>
  </table>
</div>

Scroll down **Receiver Configurations** window and select **Enter** button.

<div style="text-align: center;">
  <table>
    <tr style="vertical-align:middle;">
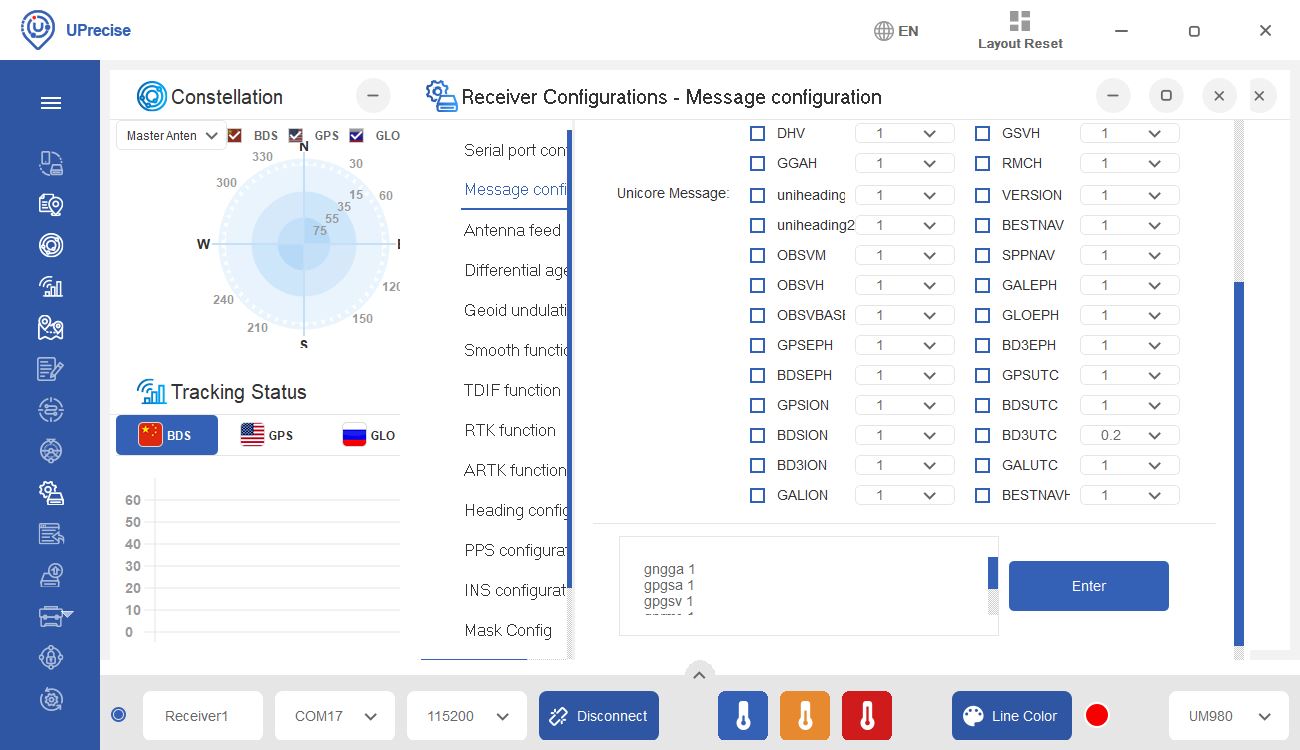
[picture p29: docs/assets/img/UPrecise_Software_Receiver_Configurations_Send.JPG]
UPrecise Software: Receiver Configurations - Message configuration, Enter
     <td style="text-align: center; vertical-align: middle;"></td>
    </tr>
  </table>
</div>

You should be able to see messages outputting through the serial terminal and displaying graphically.

<div style="text-align: center;">
  <table>
    <tr style="vertical-align:middle;">
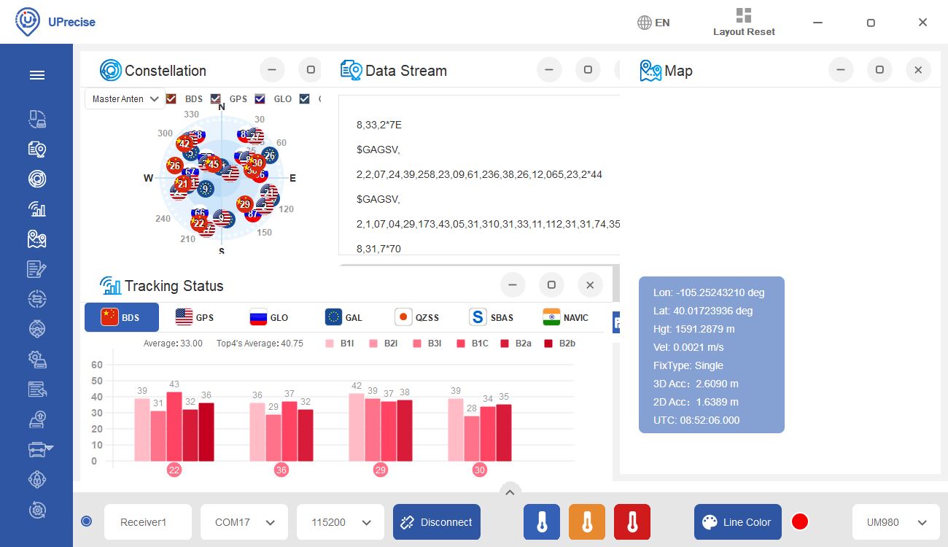
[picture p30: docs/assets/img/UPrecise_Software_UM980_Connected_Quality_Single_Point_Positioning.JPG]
UPrecise Software with UM980 Outputting Messages with Data Single Point Positioning
     <td style="text-align: center; vertical-align: middle;"></td>
    </tr>
  </table>
</div>

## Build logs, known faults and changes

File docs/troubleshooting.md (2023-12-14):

### General Troubleshooting Help

!!! note
    <span class="glyphicon glyphicon-question-sign" aria-hidden="true"></span>
        <strong> Not working as expected and need help? </strong> <br /><br />

    If you need technical assistance and more information on a product that is not working as you expected, we recommend heading on over to the <a href="https://www.sparkfun.com/technical_assistance">SparkFun Technical Assistance</a> page for some initial troubleshooting. <br /><br />

    <div style="text-align: center"><a href="https://www.sparkfun.com/technical_assistance" target="sfe_technical_assistance" class="md-button">SparkFun Technical Assistance Page</a></div>

    If you don't find what you need there, the <a href="https://forum.sparkfun.com/">SparkFun Forums</a> are a great place to find and ask for help. If this is your first visit, you'll need to <a href="https://forum.sparkfun.com/ucp.php?mode=register">create a Forum Account</a> to search product forums and post questions.<br /><br />

    <div style="text-align: center"><a href="https://forum.sparkfun.com/ucp.php?mode=register" class="md-button">Create New Forum Account</a>&nbsp;&nbsp;&nbsp;<a href="https://forum.sparkfun.com/viewforum.php?f=180" class="md-button md-button--primary">Log Into SparkFun Forums</a></div>

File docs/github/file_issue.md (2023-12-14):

# Did we make a mistake?

Spot something wrong? Please let us know. 

!!! attention
    This is not where customers should seek assistance on a product. If you require technical assistance or have questions about a product that is not working as expected, please head over to the [SparkFun Technical Assistance](https://www.sparkfun.com/technical_assistance) page for some initial troubleshooting.
    <center>
    [SparkFun Technical Assistance Page](https://www.sparkfun.com/technical_assistance){ .md-button .md-button--primary }
    </center>

    If you can't find what you need there, you'll need a [Forum Account](https://forum.sparkfun.com/ucp.php?mode=register) to search product forums and post questions.

## Discrepancies in the Documentation

All of this documentation can be modified by you! Please help us make it better.

* The documentation files for these pages are contained in the [`docs` folder of the SparkFun Triband GNSS RTK Breakout repository](https://github.com/sparkfun/SparkFun_UM980_Triband_GNSS_RTK_Breakout/tree/main/docs).

### Spot something wrong?
If a section of the documentation is incorrect, please [open an issue](https://github.com/sparkfun/SparkFun_UM980_Triband_GNSS_RTK_Breakout/issues) and let us know.

### Do you have a suggested correction?
1. With a GitHub account, fork this repo
2. Add your correction(s) or improvement(s) to the markdown file(s)
3. File a pull request with your changes, and enjoy making the ~~words~~ ~~worlds~~ world a better place.
    * Once received, the documentation specialist will automatically be notified.
    * We will review your suggested improvement(s) to make sure they are correct and fit within our documentation standards.

## Problems in the Hardware Design

All of our designs are open-source! Please help us make it better.

* Our board design files are contained in the [`Hardware` folder of the SparkFun Triband GNSS RTK Breakout repository](https://github.com/sparkfun/SparkFun_UM980_Triband_GNSS_RTK_Breakout/tree/main/Hardware).

### Does something not make sense?
If part of the design is confusing, please [open an issue](https://github.com/sparkfun/SparkFun_UM980_Triband_GNSS_RTK_Breakout/issues) and let us know.

### Did we forget to include an important function of the board?
* Please keep in mind that we may intentionally exclude certain functions of the board to meet our product design requirements. *(For example, our Qwiic Micro boards are intended to fit on a small board layout and only use I<sup>2</sup>C communication; therefore, we may not have the SPI and interrupt pins available for users.)*
* If part of the board's functionality is missing, please [open an issue](https://github.com/sparkfun/SparkFun_UM980_Triband_GNSS_RTK_Breakout/issues) and file a feature request.

### Do you wish to contribute directly to improving the board design?
1. With a GitHub account, Fork this repo
2. Add your design improvement(s)
3. File a pull request with your changes, and enjoy making the ~~words~~ ~~worlds~~ world a better place.
    * Once received, the engineer in charge of the original design will automatically be notified.
    * We will review your suggested improvement(s), if they are within our board design standards and meet our product design requirements, we will flag these changes for our next board revision. *(Please note, that even if your suggestion is accepted, these changes may not be immediate. We may have to cycle through our current product inventory first.)*

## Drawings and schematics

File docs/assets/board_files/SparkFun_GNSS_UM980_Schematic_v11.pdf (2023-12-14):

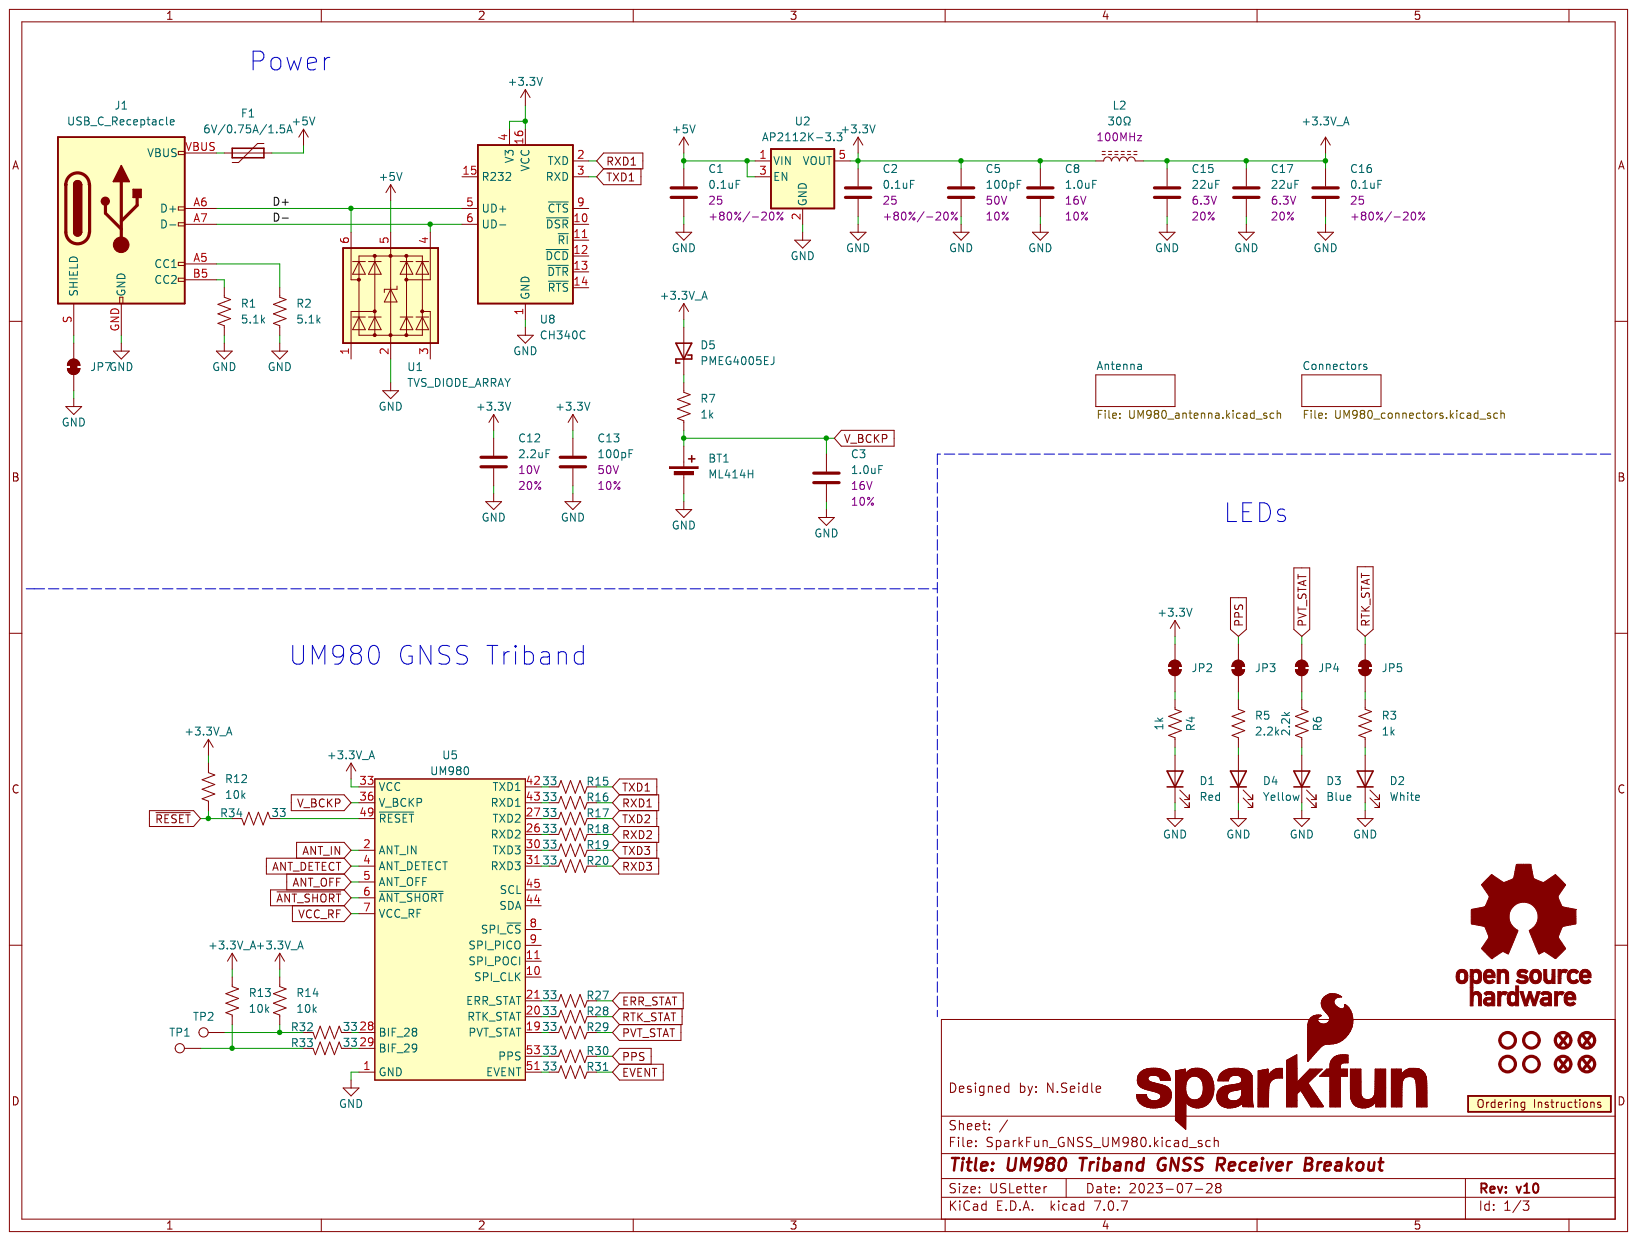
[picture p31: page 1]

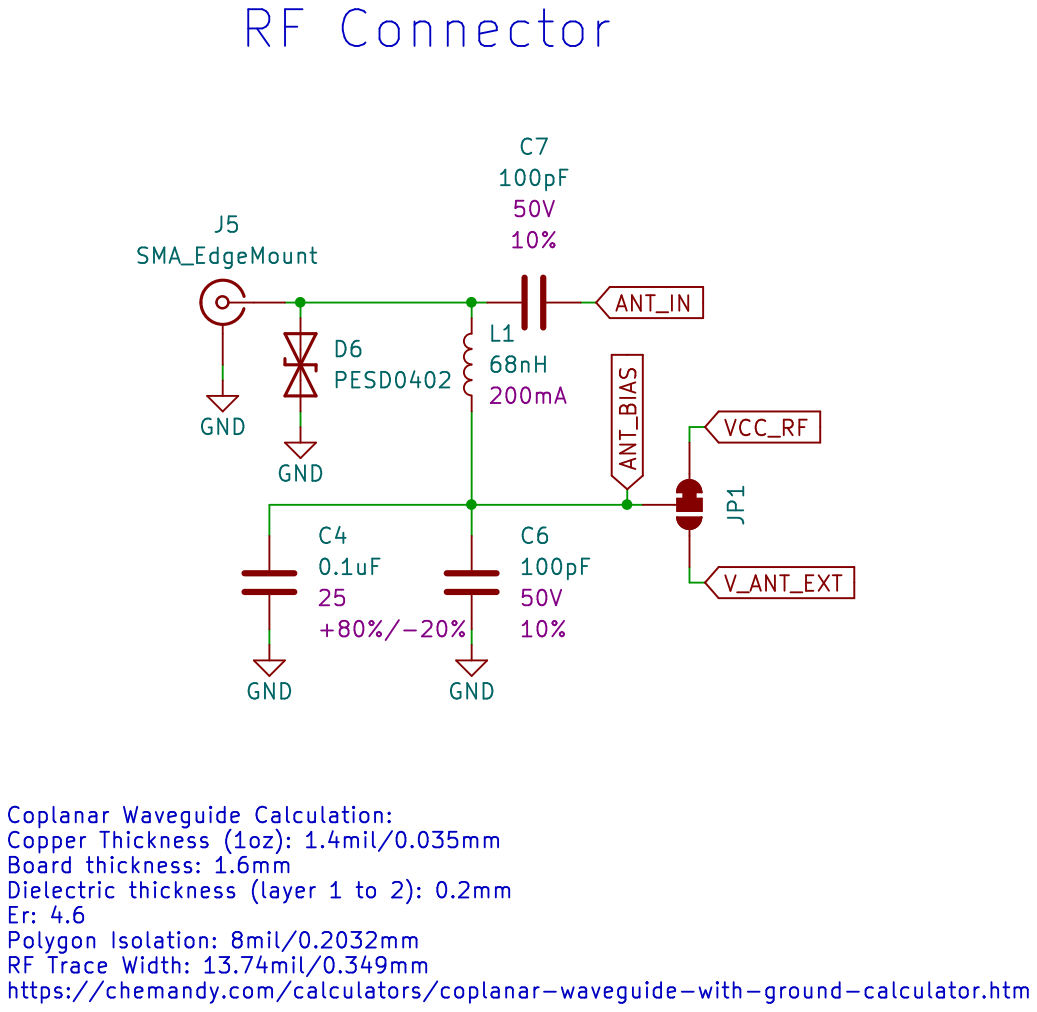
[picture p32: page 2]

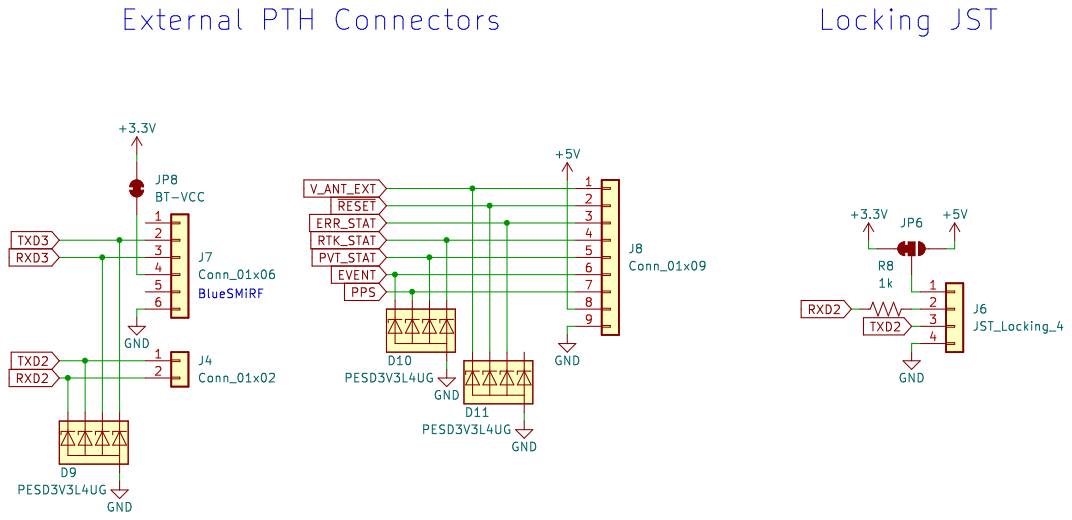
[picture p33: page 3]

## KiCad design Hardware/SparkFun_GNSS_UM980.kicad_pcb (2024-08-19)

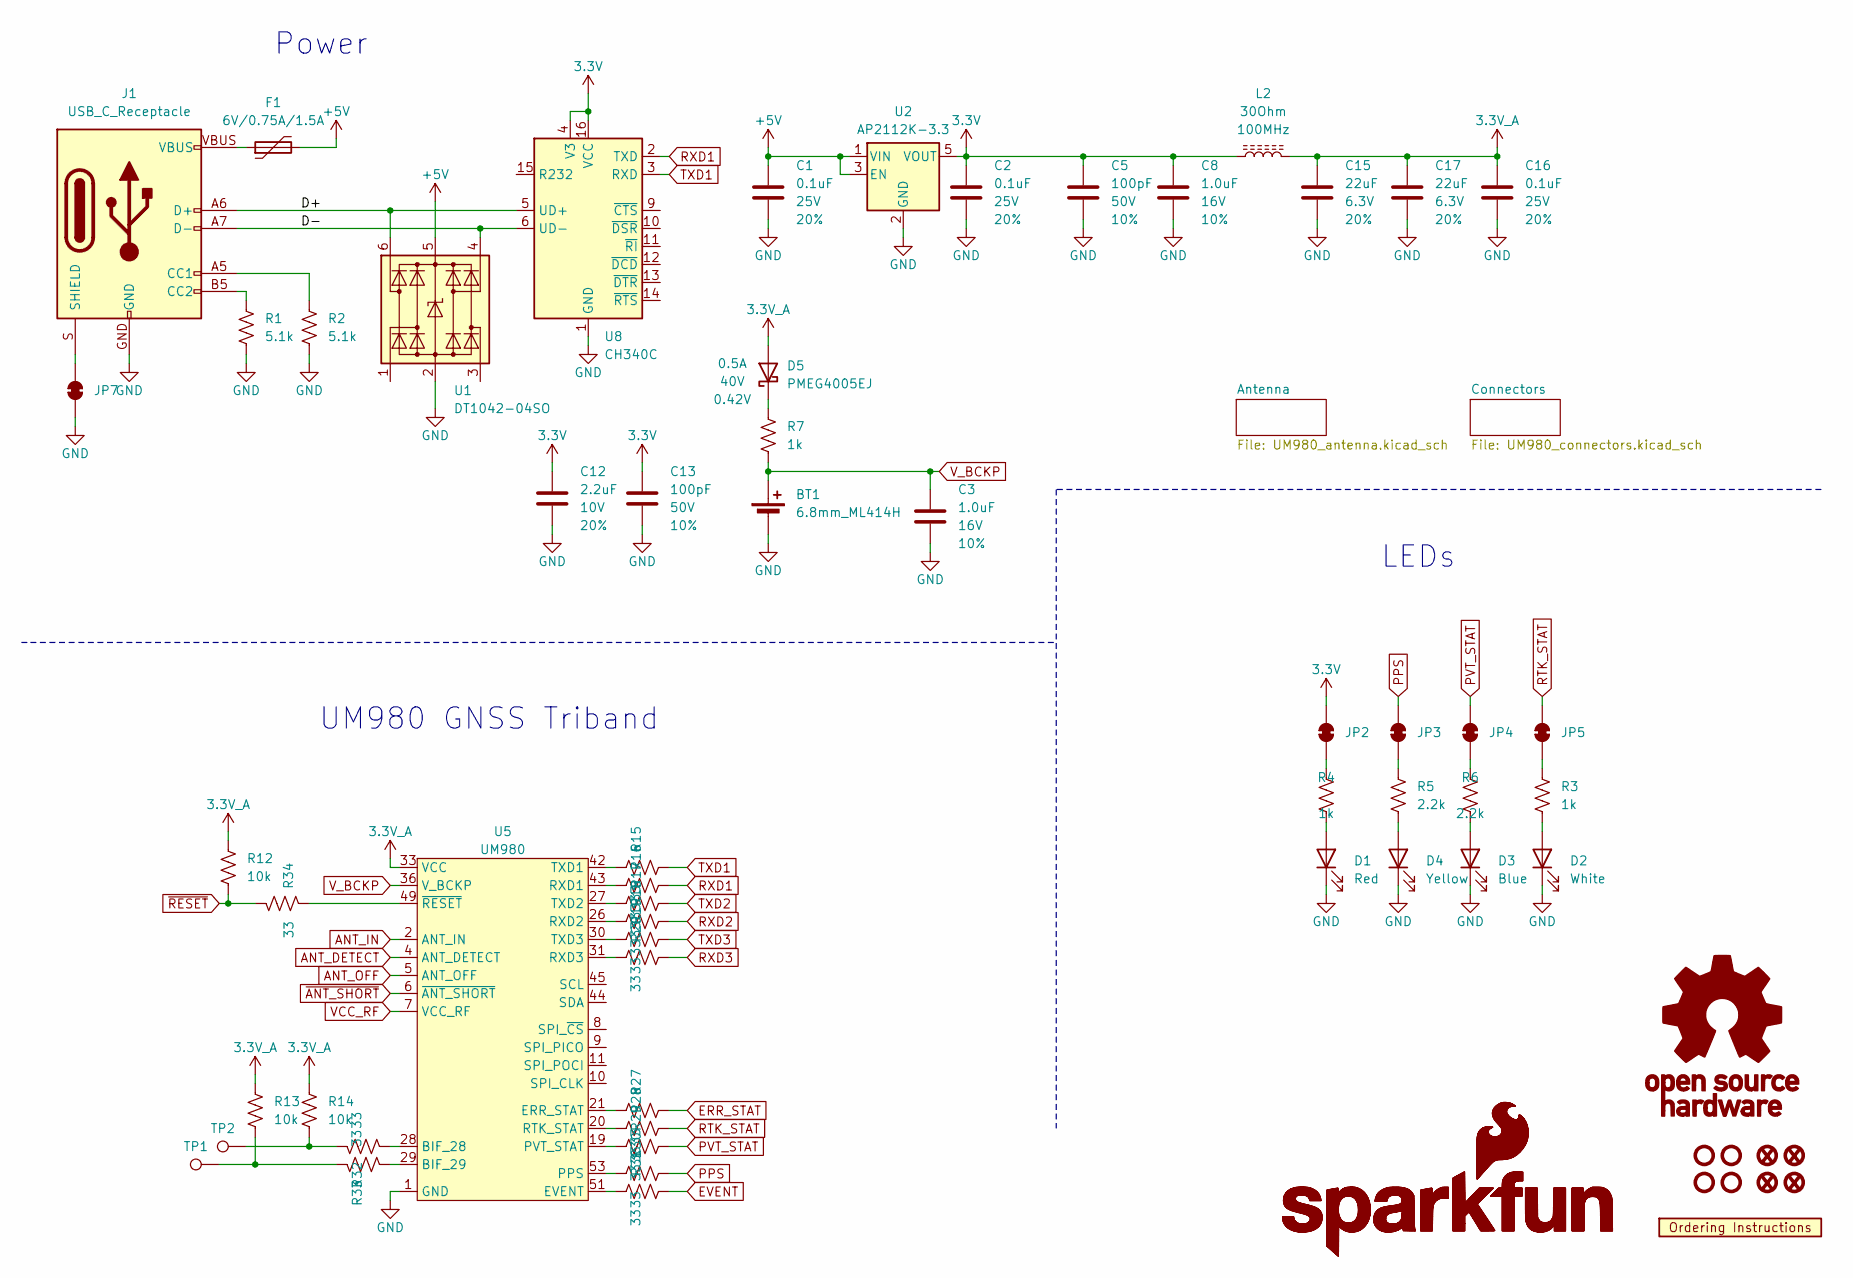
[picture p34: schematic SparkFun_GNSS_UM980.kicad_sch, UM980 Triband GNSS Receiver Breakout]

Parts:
BT1: 6.8mm_ML414H; ML414H_IV01E
C1, C2, C16: 0.1uF; C_0603_1608Metric; Voltage 25V; Tolerance 20%
C3, C8: 1.0uF; C_0603_1608Metric; Voltage 16V; Tolerance 10%
C5, C13: 100pF; C_0603_1608Metric; Voltage 50V; Tolerance 10%
C12: 2.2uF; C_0603_1608Metric; Voltage 10V; Tolerance 20%
C15, C17: 22uF; C_0603_1608Metric; Voltage 6.3V; Tolerance 20%
D1: Red; LED_0603_1608Metric_Red
D2: White; LED_0603_1608Metric_White
D3: Blue; LED_0603_1608Metric_Blue
D4: Yellow; LED_0603_1608Metric_Yellow
D5: PMEG4005EJ; SOD-323
F1: 6V/0.75A/1.5A; 1206
FID1, FID2, FID3, FID4: Fiducial_0.5mm; Fiducial_0.5mm_Mask1mm
G1: OSHW_Logo; Creative_Commons_License
G3: SparkFun_Logo
G5: SparkFun_Logo; SparkFun_Logo_8mm
J1: USB_C_Receptacle; USB-C_16
JP2, JP3, JP4, JP5, JP7: Jumper_2_NC_Trace
L2: 30Ohm; C_0603_1608Metric
R1, R2: 5.1k; R_0603_1608Metric
R3, R4, R7: 1k; R_0603_1608Metric
R5, R6: 2.2k; R_0603_1608Metric
R12, R13, R14: 10k; R_0603_1608Metric
R15, R16, R17, R18, R19, R20, R27, R28, R29, R30, R31, R32, R33, R34: 33; R_0603_1608Metric
ST1, ST2, ST3, ST4: Standoff
TP1, TP2: PTH; 1x01
U1: DT1042-04SO; SOT23-6
U2: AP2112K-3.3; SOT23-5
U5: UM980
U7: Ordering_Instructions
U8: CH340C; SO-16

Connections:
3.3V: C2.1, C5.1, C8.1, C12.1, C13.1, JP2.2 (B), L2.1, U2.5 (VOUT), U8.4 (V3), U8.16 (VCC); also elsewhere on the board
3.3V_A: C15.1, C16.1, C17.1, D5.A, L2.2, R12.1, R13.1, R14.1, U5.33 (VCC), U5.34 (VCC)
+5V: C1.1, F1.2, U1.5 (VCC), U2.1 (VIN), U2.3 (EN); also elsewhere on the board
/D+: J1.A6 (D+), J1.B6 (D+), U1.6 (I/O4), U8.5 (UD+)
/D-: J1.A7 (D-), J1.B7 (D-), U1.4 (I/O3), U8.6 (UD-)
ANT_DETECT: U5.4 (ANT_DETECT)
ANT_IN: U5.2 (ANT_IN); also elsewhere on the board
ANT_OFF: U5.5 (ANT_OFF)
ERR_STAT: R27.2; also elsewhere on the board
EVENT: R31.2; also elsewhere on the board
GND: BT1.-, C1.2, C2.2, C3.2, C5.2, C8.2, C12.2, C13.2, C15.2, C16.2, C17.2, D1.1 (K), D2.1 (K), D3.1 (K), D4.1 (K), J1.GND, JP7.1 (A), R1.2, R2.2, U1.2 (GND), U2.2 (GND), U5.1 (GND), U5.3 (GND), U5.12 (GND), U5.14 (GND), U5.32 (GND), U5.37 (GND), U5.41 (GND), U5.48 (GND), U5.55 (GND), U5.56 (GND), U5.57 (GND), U5.58 (GND), U5.59 (GND), U5.60 (GND), U5.61 (GND), U5.62 (GND), U5.63 (GND), U5.64 (GND), U5.65 (GND), U5.66 (GND), U5.67 (GND), U5.68 (GND), U5.69 (GND), U5.70 (GND), U5.71 (GND), U5.72 (GND), U5.73 (GND), U5.74 (GND), U5.75 (GND), U5.76 (GND), U5.77 (GND), U5.78 (GND), U5.79 (GND), U5.80 (GND), U5.81 (GND), U5.82 (GND), U5.83 (GND), U5.84 (GND), U5.85 (GND), U5.86 (GND), U5.87 (GND), U5.88 (GND), U5.89 (GND), U5.90 (GND), U5.91 (GND), U5.92 (GND), U5.93 (GND), U5.94 (GND), U5.95 (GND), U5.96 (GND), U5.97 (GND), U5.98 (GND), U5.99 (GND), U5.100 (GND), U5.101 (GND), U5.102 (GND), U8.1 (GND); also elsewhere on the board
unnamed: D1.2 (A), R4.2
unnamed: D2.2 (A), R3.2
unnamed: D3.2 (A), R6.2
unnamed: D4.2 (A), R5.2
unnamed: D5.C, R7.1
unnamed: F1.1, J1.VBUS
unnamed: J1.A5 (CC1), R2.1
unnamed: J1.B5 (CC2), R1.1
unnamed: J1.S (SHIELD), JP7.2 (B)
unnamed: JP2.1 (A), R4.1
unnamed: JP3.1 (A), R5.1
unnamed: JP4.1 (A), R6.1
unnamed: JP5.1 (A), R3.1
unnamed: R13.2, R33.1, TP1.1
unnamed: R14.2, R32.1, TP2.1
unnamed: R32.2, U5.28 (BIF_28)
unnamed: R33.2, U5.29 (BIF_29)
unnamed: R27.1, U5.21 (ERR_STAT)
unnamed: R31.1, U5.51 (EVENT)
unnamed: R30.1, U5.53 (PPS)
unnamed: R29.1, U5.19 (PVT_STAT)
unnamed: R28.1, U5.20 (RTK_STAT)
unnamed: R16.1, U5.43 (RXD1)
unnamed: R18.1, U5.26 (RXD2)
unnamed: R20.1, U5.31 (RXD3)
unnamed: R15.1, U5.42 (TXD1)
unnamed: R17.1, U5.27 (TXD2)
unnamed: R19.1, U5.30 (TXD3)
unnamed: R34.1, U5.49 (~RESET)
PPS: JP3.2 (B), R30.2; also elsewhere on the board
PVT_STAT: JP4.2 (B), R29.2; also elsewhere on the board
RTK_STAT: JP5.2 (B), R28.2; also elsewhere on the board
RXD1: R16.2, U8.2 (TXD)
RXD2: R18.2; also elsewhere on the board
RXD3: R20.2; also elsewhere on the board
TXD1: R15.2, U8.3 (RXD)
TXD2: R17.2; also elsewhere on the board
TXD3: R19.2; also elsewhere on the board
VCC_RF: U5.7 (VCC_RF); also elsewhere on the board
V_BCKP: BT1.+, C3.1, R7.2, U5.36 (V_BCKP)
~ANT_SHORT: U5.6 (~ANT_SHORT)
~RESET: R12.2, R34.2; also elsewhere on the board

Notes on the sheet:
LEDs
UM980 GNSS Triband
Power

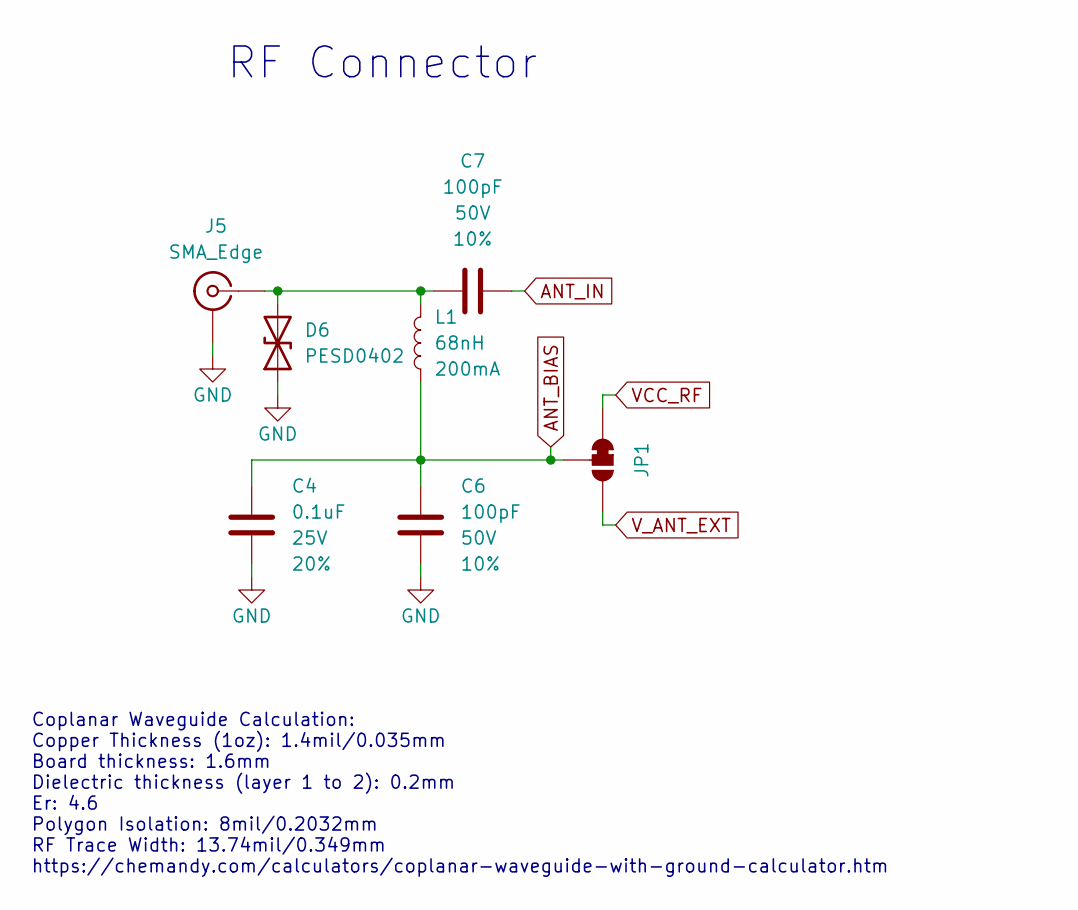
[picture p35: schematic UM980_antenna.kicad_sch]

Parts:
C4: 0.1uF; C_0603_1608Metric; Voltage 25V; Tolerance 20%
C6, C7: 100pF; C_0603_1608Metric; Voltage 50V; Tolerance 10%
D6: PESD0402; C_0402_1005Metric
J5: SMA_Edge
JP1: Jumper_3_NC-1_Trace
L1: 68nH; C_0402_1005Metric

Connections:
ANT_BIAS: C4.1, C6.1, JP1.2 (C), L1.1
ANT_IN: C7.2; also elsewhere on the board
GND: C4.2, C6.2, D6.1 (A1), J5.2 (Ext); also elsewhere on the board
unnamed: C7.1, D6.2 (A2), J5.1 (In), L1.2
VCC_RF: JP1.1 (A); also elsewhere on the board
V_ANT_EXT: JP1.3 (B); also elsewhere on the board

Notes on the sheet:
Coplanar Waveguide Calculation: Copper Thickness (1oz): 1.4mil/0.035mm Board thickness: 1.6mm Dielectric thickness (layer 1 to 2): 0.2mm Er: 4.6 Polygon Isolation: 8mil/0.2032mm RF Trace Width: 13.74mil/0.349mm https://chemandy.com/calculators/coplanar-waveguide-with-ground-calculator.htm
RF Connector

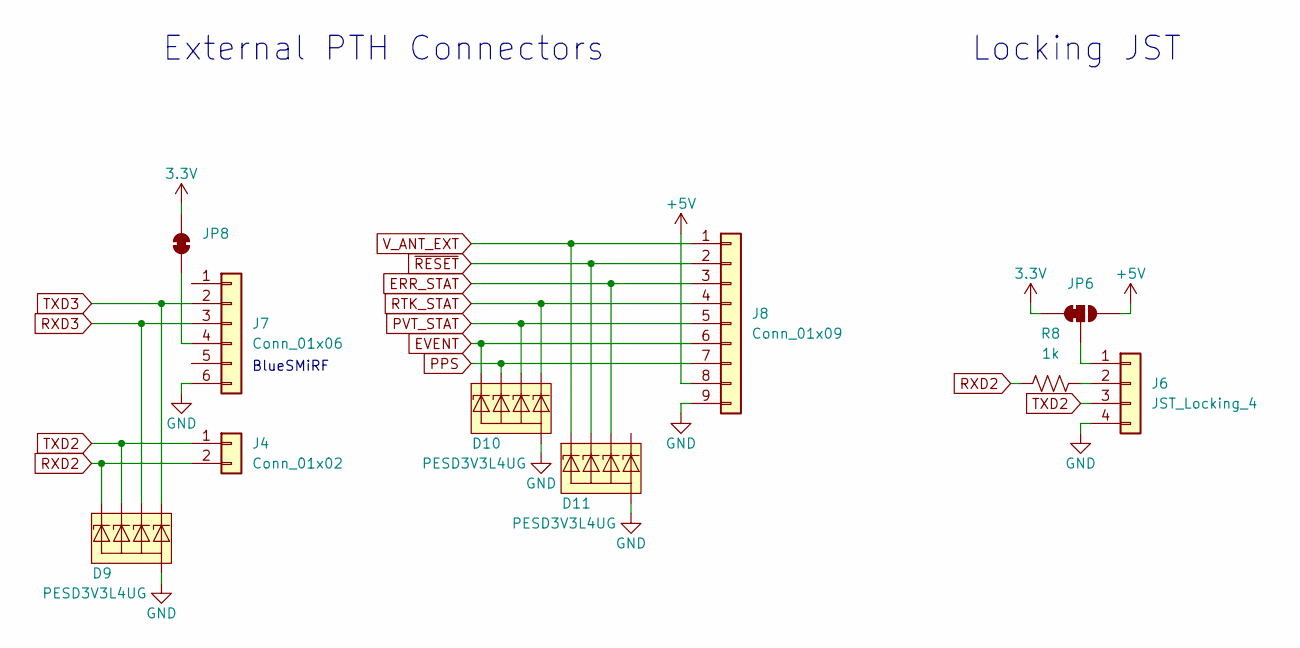
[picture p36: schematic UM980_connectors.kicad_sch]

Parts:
D9, D10, D11: PESD3V3L4UG; SOT-353
J4: Conn_01x02; 1x02
J6: JST_Locking_4; JST_SMD_1.25mm-4_Locking
J7: Conn_01x06; 1x06
J8: Conn_01x09; 1x09
JP6: Jumper_3_NC-1_Trace
JP8: Jumper_2_NC_Trace
R8: 1k; R_0603_1608Metric

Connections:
3.3V: JP6.1 (A), JP8.2 (B); also elsewhere on the board
+5V: J8.8, JP6.3 (B); also elsewhere on the board
ERR_STAT: D11.4 (K3), J8.3; also elsewhere on the board
EVENT: D10.1 (K1), J8.6; also elsewhere on the board
GND: D9.2 (A), D10.2 (A), D11.2 (A), J6.4, J7.6, J8.9; also elsewhere on the board
unnamed: J6.1, JP6.2 (C)
unnamed: J6.2, R8.2
unnamed: J7.4, JP8.1 (A)
PPS: D10.3 (K2), J8.7; also elsewhere on the board
PVT_STAT: D10.4 (K3), J8.5; also elsewhere on the board
RTK_STAT: D10.5 (K4), J8.4; also elsewhere on the board
RXD2: D9.1 (K1), J4.2, R8.1; also elsewhere on the board
RXD3: D9.4 (K3), J7.3; also elsewhere on the board
TXD2: D9.3 (K2), J4.1, J6.3; also elsewhere on the board
TXD3: D9.5 (K4), J7.2; also elsewhere on the board
V_ANT_EXT: D11.1 (K1), J8.1; also elsewhere on the board
~RESET: D11.3 (K2), J8.2; also elsewhere on the board

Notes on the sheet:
Locking JST
External PTH Connectors
BlueSMiRF

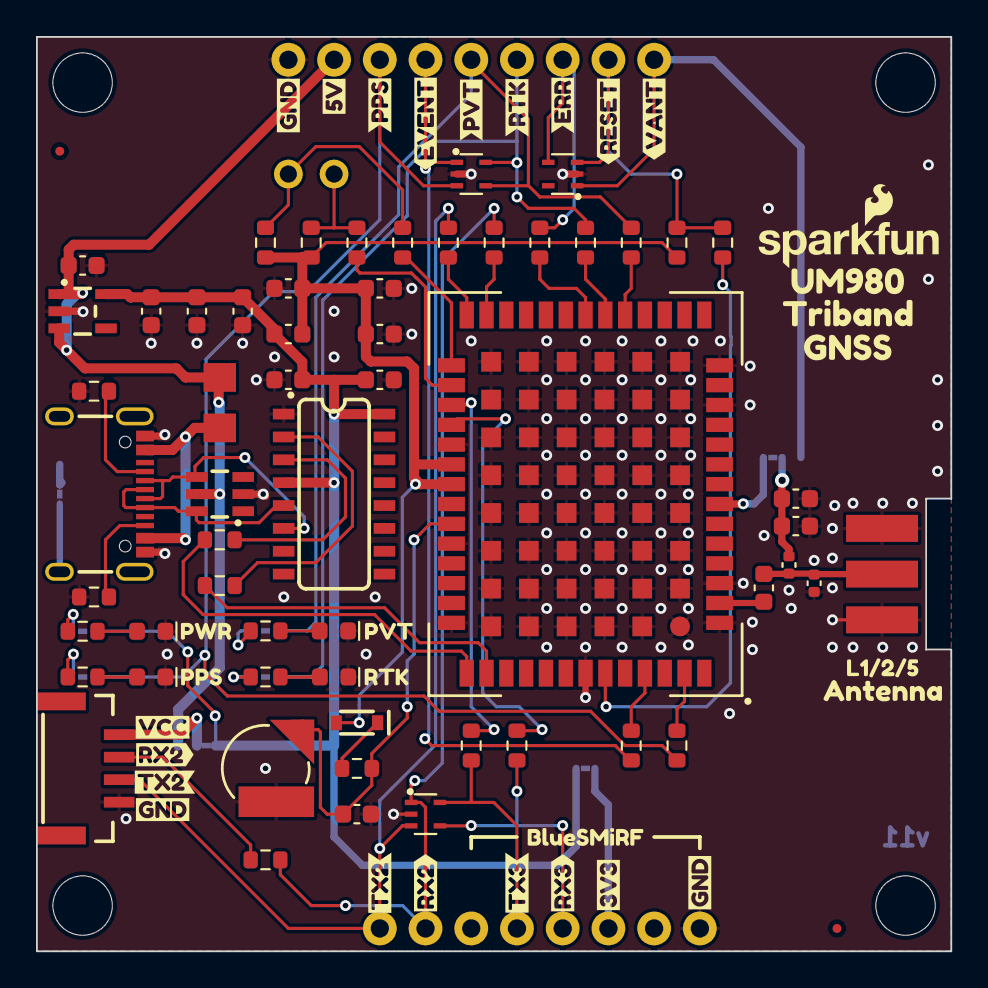
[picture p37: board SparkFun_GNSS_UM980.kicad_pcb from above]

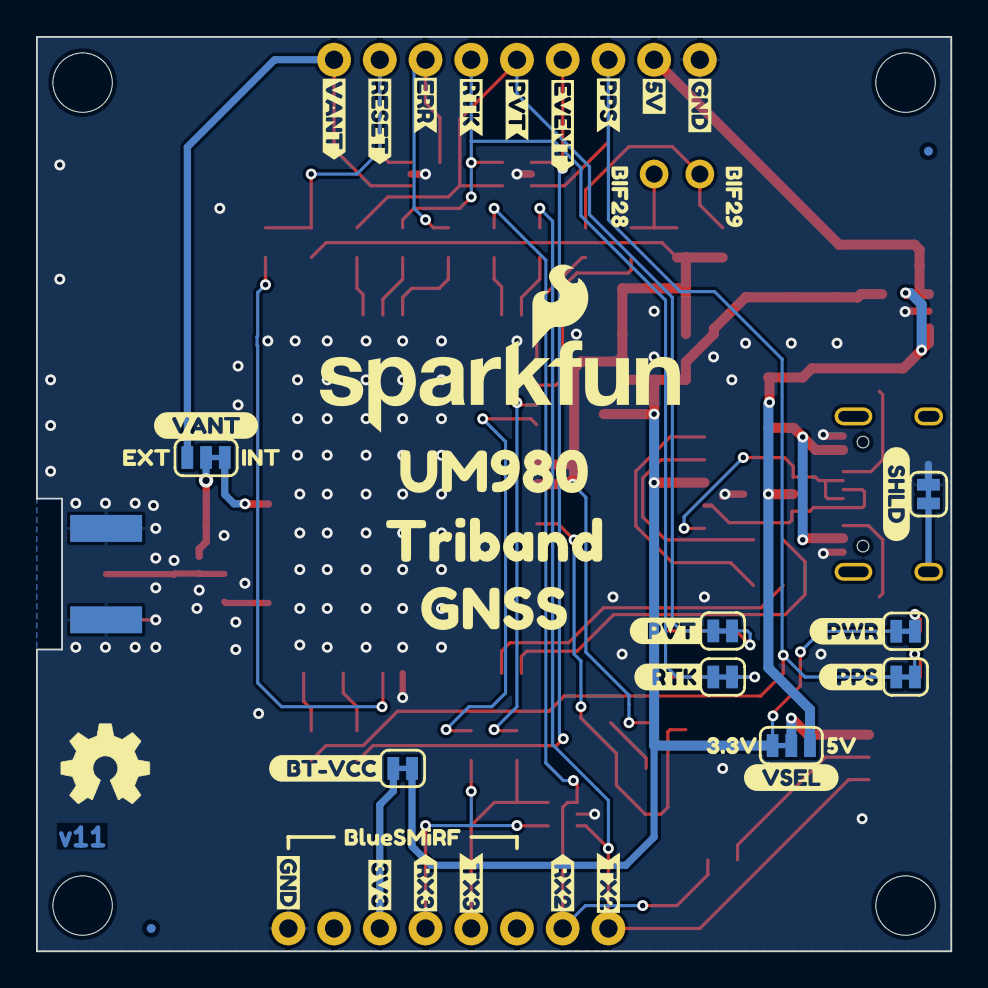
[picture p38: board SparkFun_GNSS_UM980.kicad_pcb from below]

Board: 4 copper layers, 50.8 x 50.8 mm, 144 parts (44 on the bottom side), 56 nets.

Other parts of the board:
Ref**: Val**; OSHW_Logo_5mm
kibuzzard-64C2E6A3: G***; kibuzzard-64C2E6A3
kibuzzard-64C2E6BD: G***; kibuzzard-64C2E6BD
kibuzzard-64C2E6C9: G***; kibuzzard-64C2E6C9
kibuzzard-64C2E6D6: G***; kibuzzard-64C2E6D6
kibuzzard-64C2E9A2: G***; kibuzzard-64C2E9A2
kibuzzard-64C2E77C: G***; kibuzzard-64C2E77C
kibuzzard-64C2E728: G***; kibuzzard-64C2E728
kibuzzard-64C2EADB: G***; kibuzzard-64C2EADB
kibuzzard-64C2EAF0: G***; kibuzzard-64C2EAF0
kibuzzard-64C2EB11: G***; kibuzzard-64C2EB11
kibuzzard-64C2EB16: G***; kibuzzard-64C2EB16
kibuzzard-64C3DF93: G***; kibuzzard-64C3DF93
kibuzzard-64C41486: G***; kibuzzard-64C41486
kibuzzard-64CB1646: G***; kibuzzard-64CB1646
kibuzzard-64CB1658: G***; kibuzzard-64CB1658
kibuzzard-64D296A7: G***; kibuzzard-64D296A7
kibuzzard-64D296AE: G***; kibuzzard-64D296AE
kibuzzard-64D2969C: G***; kibuzzard-64D2969C
kibuzzard-64E773DA: G***; kibuzzard-64E773DA
kibuzzard-64E773E5: G***; kibuzzard-64E773E5
kibuzzard-64E774A4: G***; kibuzzard-64E774A4
kibuzzard-64E774AA: G***; kibuzzard-64E774AA
kibuzzard-64E774B1: G***; kibuzzard-64E774B1
kibuzzard-64E774B8: G***; kibuzzard-64E774B8
kibuzzard-64E774C0: G***; kibuzzard-64E774C0
kibuzzard-64E774C8: G***; kibuzzard-64E774C8
kibuzzard-64E774E1: G***; kibuzzard-64E774E1
kibuzzard-64E774E7: G***; kibuzzard-64E774E7
kibuzzard-64E774EF: G***; kibuzzard-64E774EF
kibuzzard-64E774F5: G***; kibuzzard-64E774F5
kibuzzard-64E774FC: G***; kibuzzard-64E774FC
kibuzzard-64E7749D: G***; kibuzzard-64E7749D
kibuzzard-64E7750F: G***; kibuzzard-64E7750F
kibuzzard-64E7751D: G***; kibuzzard-64E7751D
kibuzzard-64E7752B: G***; kibuzzard-64E7752B
kibuzzard-64E7753A: G***; kibuzzard-64E7753A
kibuzzard-64E7754F: G***; kibuzzard-64E7754F
kibuzzard-64E77494: G***; kibuzzard-64E77494
kibuzzard-64E77501: G***; kibuzzard-64E77501
kibuzzard-64E77509: G***; kibuzzard-64E77509
kibuzzard-64E77517: G***; kibuzzard-64E77517
kibuzzard-64E77524: G***; kibuzzard-64E77524
kibuzzard-64E77534: G***; kibuzzard-64E77534
kibuzzard-64E77542: G***; kibuzzard-64E77542
kibuzzard-64E77548: G***; kibuzzard-64E77548
kibuzzard-64E77555: G***; kibuzzard-64E77555
kibuzzard-64ED068F: G***; kibuzzard-64ED068F
kibuzzard-64ED0510: G***; kibuzzard-64ED0510
kibuzzard-64ED0536: G***; kibuzzard-64ED0536
kibuzzard-64ED0547: G***; kibuzzard-64ED0547
kibuzzard-64ED0553: G***; kibuzzard-64ED0553
kibuzzard-64ED0645: G***; kibuzzard-64ED0645
kibuzzard-64ED0652: G***; kibuzzard-64ED0652
kibuzzard-64ED0681: G***; kibuzzard-64ED0681
kibuzzard-6501FDDA, kibuzzard-6501FDDA#2: G***; kibuzzard-6501FDDA
kibuzzard-650880D6: G***; kibuzzard-650880D6
kibuzzard-650880DF: G***; kibuzzard-650880DF
kibuzzard-650880E6: G***; kibuzzard-650880E6
kibuzzard-650885D8: G***; kibuzzard-650885D8
kibuzzard-65087150: G***; kibuzzard-65087150
kibuzzard-65087158: G***; kibuzzard-65087158

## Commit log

2023-07-28 Remove old files
    [Qwiic GPS-RTK2 - ublox ZED-F9P-Panel.GBL, Qwiic GPS-RTK2 - ublox ZED-F9P-Panel.GBO, Qwiic GPS-RTK2 - ublox ZED-F9P-Panel.GBP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]
2023-07-31 Add silk. Remove linked logos in sch.
    [SparkFun_UM980.kicad_pcb, SparkFun_UM980.kicad_sch]
2023-08-10 Update design with PROD_IDs
    [SparkFun_UM980.kicad_pcb, SparkFun_UM980.kicad_sch, UM980_antenna.kicad_sch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]
2023-09-13 Change port 3 to be compatible with BlueSMiRF
    [SparkFun_GNSS_UM980.kicad_pcb, SparkFun_GNSS_UM980.kicad_sch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]
2023-09-18 Post design review.
    [SparkFun_GNSS_UM980.kicad_pcb, SparkFun_GNSS_UM980.kicad_sch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]
2023-12-21 Update Cable to Longer Version
2024-08-19 Update to v8. Update models.
    [SparkFun_GNSS_UM980.kicad_pcb, SparkFun_GNSS_UM980.kicad_sch, UM980_antenna.kicad_sch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]
2024-11-15 Remove STL FIle
2024-12-06 Update SparkFun_GNSS_UM980_v11.zip
    - Update zipped KiCad Files for 3D Models

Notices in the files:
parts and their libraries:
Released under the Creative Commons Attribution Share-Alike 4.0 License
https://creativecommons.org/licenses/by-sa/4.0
